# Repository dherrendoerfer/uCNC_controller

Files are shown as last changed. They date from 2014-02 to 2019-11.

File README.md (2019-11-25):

Copyright (C) 2014,2015,2016,2017 D.Herrendoerfer 

# uCNC_controller: A small Arduino CNC

uCNC_controller is a small CNC G-Code interpreting controller for educational or home projects.  
It supports small set of commands and can be configured to behave in several different ways.  
Included in the Extras directory are sample files to replicate a controller circuit board and  
3D files to build a small 3 axis CNC plotter.

### uCNC_controller:
It controls up to three stepper motors via the Arduino stepper library, as well as one servo, and  
two general purpose outputs. It is programmed for simplicity and readability more than for being  
a feature-complete g-code interpreter. It is intended to be a stepping stone for people intending  
to learn about machine control.

### The Extras:
Within the Extras directory there are tools, layout and schematic files, control firmwares to  
extend the basic use example of a simple plotter. Feel free to delve.

Please read the included **uCNC_controller/README.txt** file for more information.  
Please read the included **LICENSE** files and make sure you understand them before redistributing anything from this repo.

### More Information
The original source code of uCNC_controller was developed for this project in 2013  
<a href="http://www.youtube.com/watch?feature=player_embedded&v=rLQajSRnELc
" target="_blank">Direct ink to PCB CNC Plotter</a>

Also, feel free to check out my [YouTube Channel](https://www.youtube.com/channel/UCe9XrOQuQR8SzbB_zRUIf0w "Dirk Herrendoerfers YouTube Channel")
all the source code and project files from the projects  
featured on the channel are hosted here.

### Ready to order PCBs for uCNC_Controller
The circuit boards for the uCNC projects are available for viewing at the EasyEDA online PCB design 
web site and can be ordered directly through JCLPCB from that site. 

The direct link to my project space on EasyEDA is [https://easyeda.com/dherrendoerfer](https://easyeda.com/dherrendoerfer "Dirk Herrendoerfers EasyEDA Projects")

## Notes
- The beta directory contains pre-release versions of the controller firmware.
- To build the uCNC_controller firmware the Arduino stepper library is required.
- The firmware requires a 5V Arduino board with at least 13 digital and 6 Analog I/O ports.  
- Recommended are 32k of flash memory.  
- Among the supported boards are: Arduino Uno, Arduino Nano, Arduino Mega 2560, and many more.
- This is work-in-progress. Check back frequently.

Donations:  
If you would like to make a donation to keep this project and others going you can do so at:  
https://www.paypal.me/dherrendoerfer  
This helps a lot !

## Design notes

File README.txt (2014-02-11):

 *
 * This file is part of uCNC_controller.
 *
 * Copyright (C) 2014  D.Herrendoerfer
 *
 *   uCNC_controller is free software: you can redistribute it and/or modify
 *   it under the terms of the GNU General Public License as published by
 *   the Free Software Foundation, either version 3 of the License, or
 *   (at your option) any later version.
 *
 *   uCNC_controller is distributed in the hope that it will be useful,
 *   but WITHOUT ANY WARRANTY; without even the implied warranty of
 *   MERCHANTABILITY or FITNESS FOR A PARTICULAR PURPOSE.  See the
 *   GNU General Public License for more details.
 *
 *   You should have received a copy of the GNU General Public License
 *   along with uCNC_controller.  If not, see <http://www.gnu.org/licenses/>.
 *

uCNC_controller Readme file:
============================

uCNC_controller is a g-code interpreting controller app that is intended
for use on the Arduino platform. It interprets a number of g-code 
commands and controls a number of unipolar stepper motors (3), some 
digital outputs (2), and number of servos (1) accordingly.
It is intended for use in home or educational projects, and as the 
license states: it comes with no waranty whatsoever. If you use it
and it breaks in your hands, you get to keep all the pieces.

Default configuration:
======================

  Connector   IO-Ports on Arduino nano w. ATMEGA328P
------------>--------------------------------------------
  Stepper 1:  8,9,10,11
  Stepper 2:  4,5,6,7
  Stepper 3:  A5,A4,A3,A2 (digital out 19,18,17,16)               
  12V out 1:  2
  12V out 2:  3
  Laser out:  13
  Servo out:  12
  Unused   :  A0,A1,A6,A7 (A6 and A7 cannot be used as output) 

System Reset and Initialization routine
---------------------------------------
  Upon reset or power up the controller attempts to move all
  axis into their minimal position by traversing the configured
  distance into a solid zero position block - builds should be
  designed to cope with this. 

Device-specific values and devices
==================================

Control ports:
--------------
 - Liquid coolant (M7,M8,M9) controls 12VO port 1
 - Vacuum (M10,M11) controls 12VO port 2
 - Spindle(M3,M4,M5) controls Laser and Servo ports (mode dependent)
 - Tool (TXX) controls Servo (mode dependent)
 - Z value controls Laser (on when Z negative - mode dependent)

Device-specific G-Code commands:
================================
  NOTE: All of these settings can be made in the source code of the
        controller applivation, and should in fact be made there.
        The possibility to change them is intended to make it possible
        to create a controller module that can be shared between 
        several installations, and that is configured by the init
        sequence of its controlling host.

M150: Set Z-Axis mode
---------------------
Defines the mode how the Steppers, the servo and the laser driver are
used by the controller and which codes modify their states
  Mode 0: Stepper 1 is X
          Stepper 2 is Y
          Stepper 3 is Z
          Servo is spindle speed
          Laser is driven by spindle
          
  Mode 1: Stepper 1 is X
          Stepper 2 is Y
          Stepper 3 is Y
          Servo     is Z (down for Z<0)
          Laser     is Z (on for Z<0)

  Mode 2: Stepper 1 is X
          Stepper 2 is Y
          Stepper 3 is Y
          Servo     is Z (+90 to -90)
          Laser     is driven by spindle
          
  Mode 3: Stepper 1 is X
          Stepper 2 is Y
          Stepper 3 is Y
          Servo     is tool
          Laser     is Z (on for Z<0)
          
  Sample:
    M150 S2   ;Sets mode 2
          
M151: Set servo upper position
------------------------------
Sets the maximum value to send to the servo. Range is 0 to 180.

  Sample:
    M151 S170   ;Sets the maximum position to 170

M152: Set servo lower position
------------------------------
Sets the minimum value to send to the servo. Range is 0 to 180.

  Sample:
    M152 S10   ;Sets the minimum position to 10

M153: Set servo tool increment
------------------------------
Sets the increment value to send to the servo depending on the selected tool.

  Sample:
    M153 S10   ;Sets an servo increment of 10 for each selected tool.

M154: Set servo Z factor
------------------------
Sets the ratio between the Z value and the servo position in degrees.

  Note: The Z value at factor 1 is -89 to +90, this also honors the minimum
        and max values set to the servo, so set them to 0 and 180 for full 
        stroke. The sign of this value determines the direction of the servo.

  Sample:
    M154 S0.1  ;Sets ratio to 0.1

M160: Set X-Axis step to mm ratio
---------------------------------
Sets the calibration value of the X-Axis in relation to the steps needed to
travel 1 milimeter. The sign of this value determines the direction of the 
stepper.

  Sample:
    M160 S17.1  ;Sets the ratio of the X-Axis to 17.1 steps per milimeter

M161: Set Y-Axis step to mm ratio
---------------------------------
Sets the calibration value of the Y-Axis in relation to the steps needed to
travel 1 milimeter. The sign of this value determines the direction of the 
stepper.

  Sample:
    M161 S17.1  ;Sets the ratio of the Y-Axis to 17.1 steps per milimeter

M162: Set Z-Axis step to mm ratio
---------------------------------
Sets the calibration value of the Z-Axis in relation to the steps needed to
travel 1 milimeter. The sign of this value determines the direction of the 
stepper.

  Sample:
    M162 S17.1  ;Sets the ratio of the X-Axis to 17.1 steps per milimeter

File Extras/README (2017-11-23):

Copyright (C) 2014,2015,2016 D.Herrendoerfer 

This directory contains additional files for uCNC_controller

Note:
PCB layouts now also available here: https://easyeda.com/dherrendoerfer 

Controller
----------
  The this directory contains the files to recreate a controller
  PCB using uCNC_controller and a G-Code sender.

Controller_v1
-------------
  The this directory contains the files for an updated version
  of the first control board. It also includes the original
  Eagle project files.

Controller_v4
-------------
  The this directory contains the files for an upgraded version
  of the control board. It uses A4988 stepper driver modules that
  allow the use of bipolar steppers. It also includes the original
  Eagle project files.

GcodeWriter
-----------
  This directory contains an updated version of ardGcodeWriter.py
  with a number of improvements from me.
  This was not developed by me, I only fixed a number of bugs in
  the program. As the original has been removed from the net I
  keep my latest version here for reference.
  For more information on the original Author, refer to the source
  code.
  
Hp2xx
-----
  This directory contains a Windows executable of the hp2xx tool.
  This is for reference only, but as the tool appears to be unmaintained
  at this time I keep it here. 

Plotter_v3
----------
  This directory contains the files to recreate a simple plotter that
  can be used with the uCNC_controller firmware.

Plotter_v4
----------
  This directory contains the files to recreate a simple plotter that
  can be used with the uCNC_controller firmware. This one uses NEMA 17 
  steppers.

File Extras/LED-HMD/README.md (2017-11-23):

Copyright (C) 2017 D.Herrendoerfer 

# Simple tools and instructions for building a WS2812 based round display:

The geometry of the display of lines of LEDs with the following length:

(6,10,14,16,18,20,22,22,24,24,24,26,26,26,26,24,24,24,22,22,20,18,16,14,10,6)

Like so:
```
         XXXXXX
       XXXXXXXXXX
     XXXXXXXXXXXXXX
    XXXXXXXXXXXXXXXX
   XXXXXXXXXXXXXXXXXX
  XXXXXXXXXXXXXXXXXXXX
  XXXXXXXXXXXXXXXXXXXX
 XXXXXXXXXXXXXXXXXXXXXX
 XXXXXXXXXXXXXXXXXXXXXX
 XXXXXXXXXXXXXXXXXXXXXX
XXXXXXXXXXXXXXXXXXXXXXXX
XXXXXXXXXXXXXXXXXXXXXXXX
XXXXXXXXXXXXXXXXXXXXXXXX
XXXXXXXXXXXXXXXXXXXXXXXX
 XXXXXXXXXXXXXXXXXXXXXX
 XXXXXXXXXXXXXXXXXXXXXX
 XXXXXXXXXXXXXXXXXXXXXX
  XXXXXXXXXXXXXXXXXXXX
  XXXXXXXXXXXXXXXXXXXX
   XXXXXXXXXXXXXXXXXX
    XXXXXXXXXXXXXXXX
     XXXXXXXXXXXXXX
      XXXXXXXXXX
        XXXXXX
```

The sketch will display the images, the tool will generate the source code
from an image.

There are 2 switches (to GND) on D2 and D3, one will advance to the next image,
the other will apply a variation to the image to make simple animations possible,
like a smily giving a wink.
Pressing any switch for more than 2 seconds turns off the display.

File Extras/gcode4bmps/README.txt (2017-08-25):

 *
 * This file is part of uCNC_controller.
 *
 * Copyright (C) 2017  D.Herrendoerfer
 *
 *   gcode4bmps.py is free software: you can redistribute it and/or modify
 *   it under the terms of the GNU General Public License as published by
 *   the Free Software Foundation, either version 3 of the License, or
 *   (at your option) any later version.
 *
 *   uCNC_controller is distributed in the hope that it will be useful,
 *   but WITHOUT ANY WARRANTY; without even the implied warranty of
 *   MERCHANTABILITY or FITNESS FOR A PARTICULAR PURPOSE.  See the
 *   GNU General Public License for more details.
 *
 *   You should have received a copy of the GNU General Public License
 *   along with uCNC_controller.  If not, see <http://www.gnu.org/licenses/>.
 *
 
gcode4bmps.py:
--------------

Gcode for bitmaps is a very simple tool to transform bitmaps to gcode
for raster engraving. (Engraving line by line, not vector-style)
Images read are converted to grayscale and then interpreted as black
and white (trip value 128).

Installation:
-------------

Gcode4bmps.py was developed for python2.7. It also requires the
prior installation of the python-pillow library and it's development
package (python-pillow-devel).
Futhermore, to read and interpret ps, eps, and pdf files, the ghostscript
package must be installed. (This was only tested on Linux, but should work
with Windows too.)

Usage:
------

Basic usage:

./gcode4bmps.py  -d 300 -i test/tux-bw.gif

This will read the image and generate g-code to engrave it. The output
will be written to output.nc in the current directory (default, unless specified)
You need to supply at least one of:
	- Output size with -x and -y (in mm)
	- Source image DPI with -d 
	- Source image DPCM (dots per cm) with -m 

You can specify the output file name with -g ( '-g -' for standard out, implies using -q )

Using postscript or pdf:
------------------------

/gcode4bmps.py -G -C -d 300 -i test/tux-bw.pdf

Use the -G option to turn on ghostscript transcoding, and also use
the -C option to crop the resulting image (ghostscript output is always a page)

Options available:

Usage: gcode4bmps.py [options]

Options:
  -h, --help            				show this help message and exit
  -i FILE, --imgfile=FILE				read image from this FILE
  -g FILE, --gcodefile=FILE				write gcode to this FILE
  -s STEPSIZE, --stepsize=STEPSIZE		stepsize of a single output pixel/dot (bit/laser size)
  -x XSIZE, --xsize=XSIZE				x size of the output gcode in mm
  -y YSIZE, --ysize=YSIZE				y size of the output gcode in mm
  -d DPI, --dpi=DPI     				source image dpi value
  -m DPCM, --dpcm=DPCM  				source image dpcm value
  -n, --negative        				invert the image
  -p PASSES, --passes=PASSES			number of passes over a line
  -u, --upwards         				process from bottom to top
  -z ZDOWN, --zdown=ZDOWN				value for Z axis down
  -Z ZUPPER, --zupper=ZUPPER			value for Z axis up
  -b, --bidirectional   				engrave in both directions
  -B, --backlash        				compensate for backlash in unidirectional engraving
  -f FEED1, --feed1=FEED1				set feedrate for G1 moves
  -F FEED0, --feed0=FEED0				set feedrate for G0 moves
  -M speed, --spindle=speed             enable insertion of spindle start and stop with selected speed
  -C, --crop            				crop the image to only plot the used area
  -G, --ghostscript     				use ghostscript to import postscript image files
  -q, --quiet           				don't print status messages to stdout

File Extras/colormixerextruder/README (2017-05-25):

COLORMIXEXTRUDER:

This is the attempt to build a simple color mixing
extruder driver board and controller to drive a 
diamond extruder without modifying an existing 
3D printers driver board to support more stepper
drivers.

The signals of the stepper controller board from
the 3D printers extruder stepper are passed to the 
controller as well as the serial data comming from
the PC.

The controller scans the incommming serial g-code 
data for occurences of the TXX code and sets the
desired color for that tool.

This has been designed for my uControl_v1 driver 
board but should be easily adapted for other driver
boards.

This is alpha software - expect it to be broken.

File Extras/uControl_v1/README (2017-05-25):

Included here is a prototype layout for a controller circuit.

The uControl board is different from the previous versions and 
requires a different firmware than the other versions.

Features are:
--------------
Support for 3 bipolar steppers using A4988 Polulu driver modules.
Support for 1 servo
Support for 8 input lines 6 bare, 2 as switch inputs
Support for 1 high load output (5A/PWM)
Support for breakout of serial and reset lines

uControl_v1.sch
----------------
  The layout schematic file

uControl_v1.brd
----------------
  The layout source file (just the layout)

uControl_v1.ps, uControl_v1.pdf
--------------------------------
  Exported layout formats of the above board

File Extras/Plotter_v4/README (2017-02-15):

Sample stl model files to make a plotter using a 3D printer.

Other needed parts list:

The 3D parts in this directory (Plotter-v4-AllParts.stl) once, 
and the parts for the pen-holder from the Plotter_v3 directory.

Other parts required:

Quan.|  Item
-----+----------------------------------------------
4	  	5mm steel rod. 
some	Brass tube, 6mm outer, 5mm inner diameter
2 		NEMA 17 Stepper Motors
some	T2 or T2.5 belt 6mm width for X and Y Axis
2		T2 or T2.5 belt pulleys
2 		Ball bearings 11/5mm
1 		20mm micro servo
8		Magnets (5/1mm)
some 	PCB prototyping board

Parts list for the controller:

Quan.|  Item
-----+----------------------------------------------
1 		Arduino nano with 328P 
2		Polulu Stepper driver modules
1		7805 Power regulator
1		Capacitor 1000uF/25V (input smoothing)
1		Capacitor 100uF/10V  (5V smoothing)
		Male Connectors for Motors and Arduino
		Female pin connectors for Servo and Laser out.
Optional
		Mosfet and Resistor for Laser driver
		(Choose what you need, depends on laser type)

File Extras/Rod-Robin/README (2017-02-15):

This list is work-in-progress (might be incomplete)

Sample stl model files to make the Rod-Robin CNC using a 3D printer.

Other needed parts list:

The 3D parts in this directory according to list below.

Quan.|  Item
-----+----------------------------------------------
 1   | Rod-Robin-Pillar-A.stl
 1   | Rod-Robin-Pillar-B.stl
 2   | Rod-Robin-H-Base-A.stl
 2   | Rod-Robin-H-Base-B.stl
 1   | Rod-Robin-H-Base-C.stl  
 4   | Rod-Robin-H-Base-D.stl  
 2   | Rod-Robin-Table-A.stl  
 1   | Rod-Robin-Z-Base-A.stl  

Other parts required:

Quan.|  Item
-----+----------------------------------------------
 7	 | 	LM5UU Linear bearings. 
 6   |	11x5x4 Bearings 
 2 	 |	NEMA 17 Stepper Motors
 2	 |	T2 or T2.5 belt 6mm width
 2	 |	T2 or T2.5 belt pulleys
 2   |  Microswitches
 4   |  5mm Stainless Steel rod 
     |    2x for X-Axis 
     |    2x for Y-Axis
16	 |  M5 Threaded Rod
many |  M5 Nuts
 1   |  Table board 
     |    2 to 4mm steel or aluminium 
 
Also needed:
  Glue (Pattex Clasic)
  Nut-Lock glue ( Locktite medium )

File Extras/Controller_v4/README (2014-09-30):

Included here is a prototype layout for a controller circuit.

The Controller_v4 is different from the previous versions and 
requires a different firmware than the other versions.

New features are:
-----------------
Support for 3 bipolar Steppers using A4988 Polulu driver modules.
Support for 1 unipolar Stepper using a ULN2003
Support for 1 Servo 
Support for 3 GPIO outputs 500mA
Support for 1 high load output (5A)
Support for 2 signal inputs

Controller_v4.sch
-----------------
  The layout schematic file

Controller_v4.brd
-----------------
  The layout source file (just the layout)

Controller_v4.hpgl, Controller_v4.ps, Controller_v4.pdf
-------------------------------------------------------
  Exported layout formats of the above board

Controller_v4.hpgl.nc
---------------------
  A g-code sample file that will produce a plot of the above
  board using the included board and firmware.

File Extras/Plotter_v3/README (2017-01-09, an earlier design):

Sample stl model files to make a plotter using a 3D printer.

Other needed parts list:

The 3D parts in this directory ( Plotter-v3-PenMount-2.stl twice)
or the Plotter-v3-AllParts.stl once, it contains everything except the
table, which is optional and can easily be replaced by some prototyping
board.

Please note that the maximum size of this plotter can be quite large,
but to minimize the elastic effect of the nylon string I advise to keep
the X axis at about 20cm and the Y Axis at 16cm. The steel rods need to
be 2cm larger for the X axis (24cm) and 6cm for the Y Axis (24cm).

Other parts required:

Quan.|  Item
-----+----------------------------------------------
4	  	5mm steel rod. 
some	Brass tube, 6mm outer, 5mm inner diameter
2 		Stepper Motors 28YBJ-48 (12V or 5V)
2 		Ball bearings 4/2mm
1 		20mm micro servo
8		Magnets (5/1mm)
some	Nylon string or fishing line
some	PCB prototyping board

Parts list for the controller:

Quan.|  Item
-----+----------------------------------------------
1 		Arduino nano with 328P 
2		ULN2003 or ULN2004
1		7805 Power regulator
1		Capacitor 1000uF/25V (input smoothing)
1		Capacitor 100uF/10V  (5V smoothing)
		Male Connectors for Motors and Arduino
		Female pin connectors for Servo and Laser out.
Optional
		Mosfet and Resistor for Laser driver
		(Choose what you need, depends on laser type)

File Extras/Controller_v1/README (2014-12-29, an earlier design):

Included here is a prototype layout for a controller circuit.
This controller circuit is identical to the Controller.brd 
with the exception that the Laser is driven with 12V, not 5V.

-- Beta warning: this has not jet been fully tested by me.

Controller_v1.brd
--------------
  The layout source file

Controller_v1.sch
--------------
  The schematic source file.

  Controller_v1.hpgl, Controller_v1.ps
--------------------------------------
  Exported layout formats of the above board

Controller_v1.hpgl.nc
---------------------
  A g-code sample file that will produce a plot of the above
  board using the included board and firmware.

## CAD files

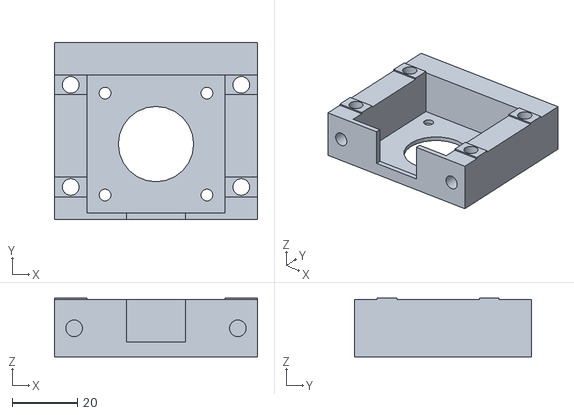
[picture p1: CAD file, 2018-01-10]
Extras/Plotter_v4/Plotter_v4_Table_Base_1.stl
62.0 x 54.0 x 18.0

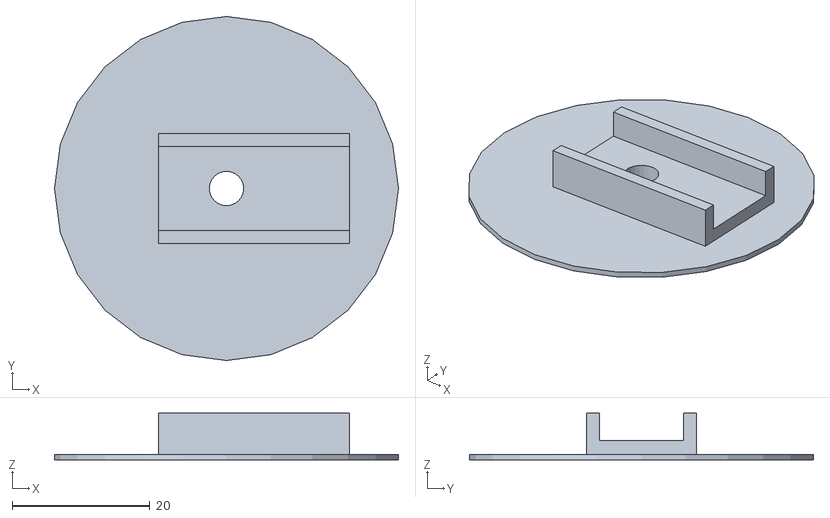
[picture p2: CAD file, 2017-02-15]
Extras/Rod-Robin/Laser-Tool/Rod-Robin-Laser-Tool-C.stl
50.0 x 50.0 x 6.80

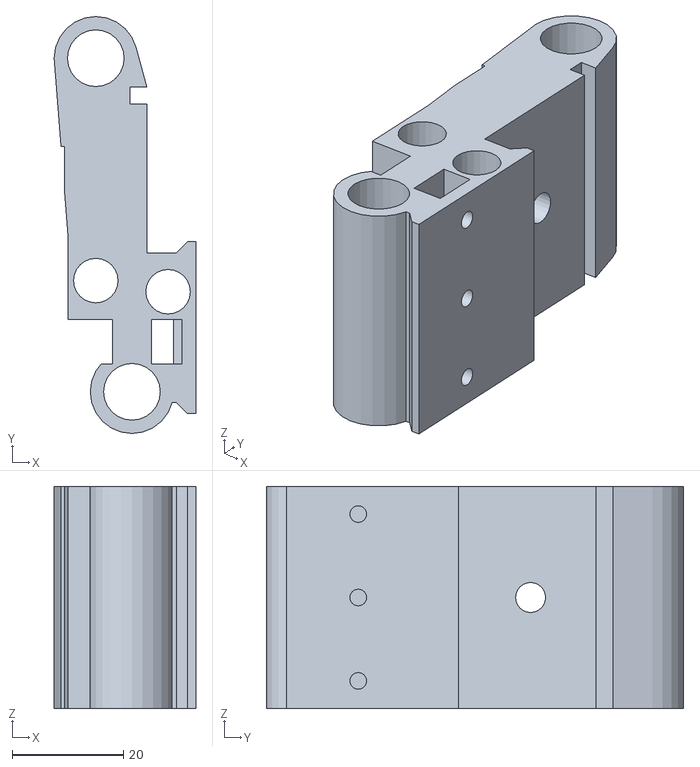
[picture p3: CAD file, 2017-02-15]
Extras/Rod-Robin/Rod-Robin-Z-Base.stl
25.5 x 75.0 x 40.0

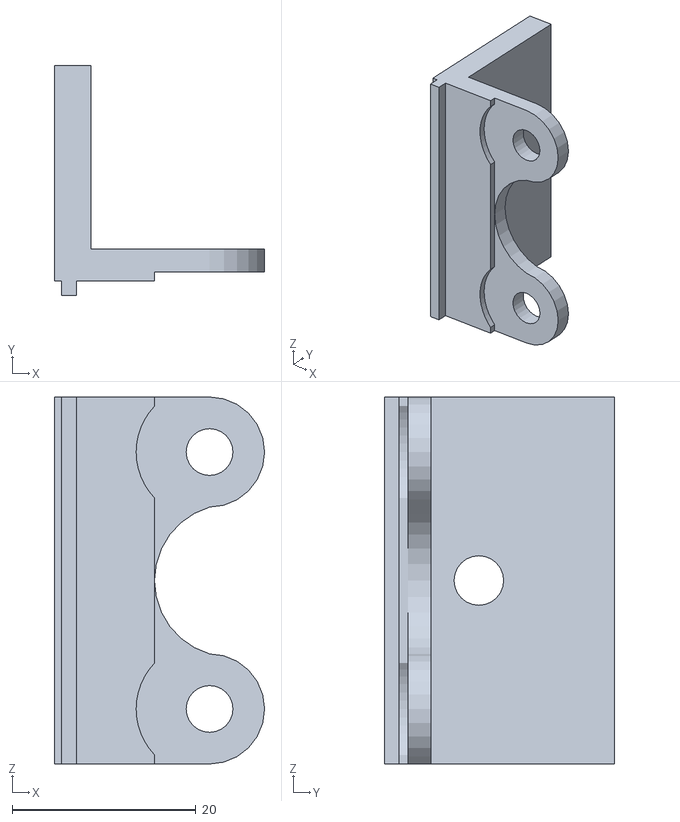
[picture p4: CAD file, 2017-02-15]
Extras/Rod-Robin/Z-Axis-Tool/Rod-Robin-Z-Tool_B.stl
22.9 x 25.1 x 40.0

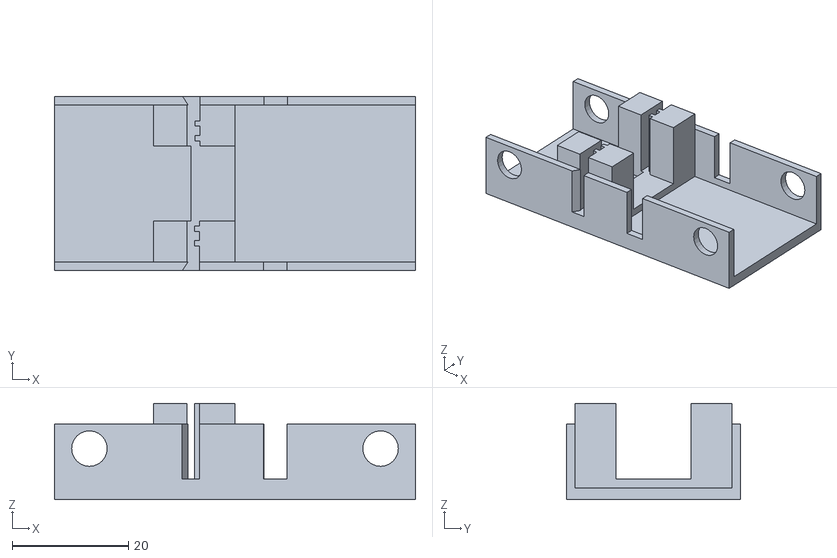
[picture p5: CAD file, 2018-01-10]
Extras/Plotter_v4/Plotter_v4_Table_Sled.stl
62.0 x 30.0 x 16.5

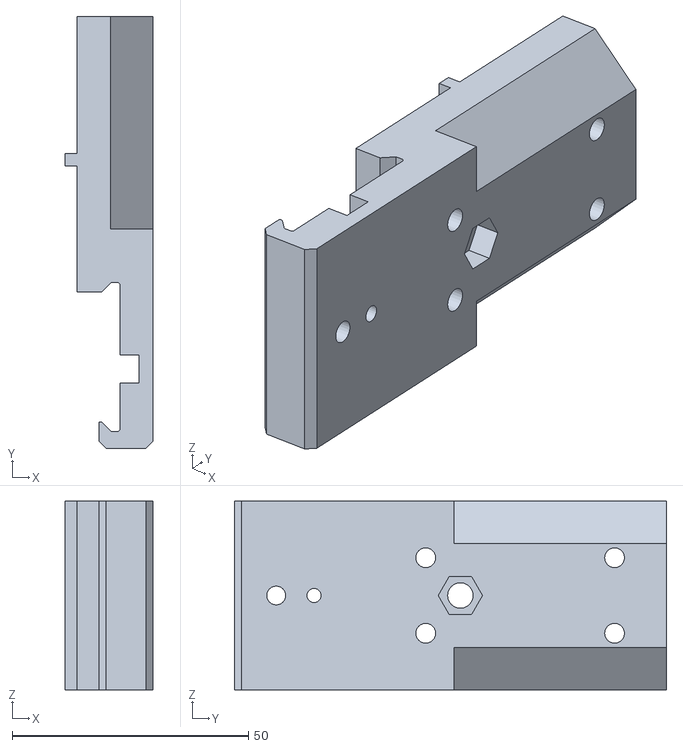
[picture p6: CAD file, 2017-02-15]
Extras/Rod-Robin/Laser-Tool/Rod-Robin-Laser-Tool-A.stl
18.6 x 91.5 x 40.0

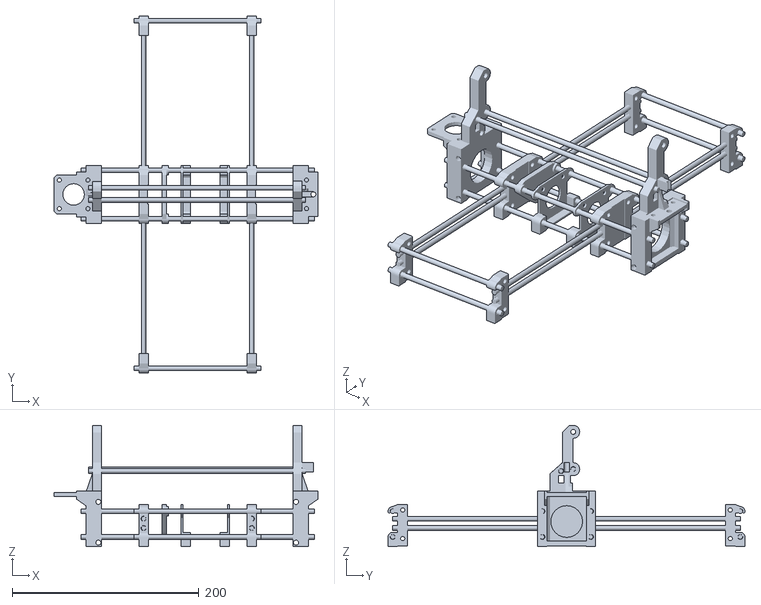
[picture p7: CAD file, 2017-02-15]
Extras/Rod-Robin/Rod-Robin-v2.stl
282.5 x 382.0 x 130.0

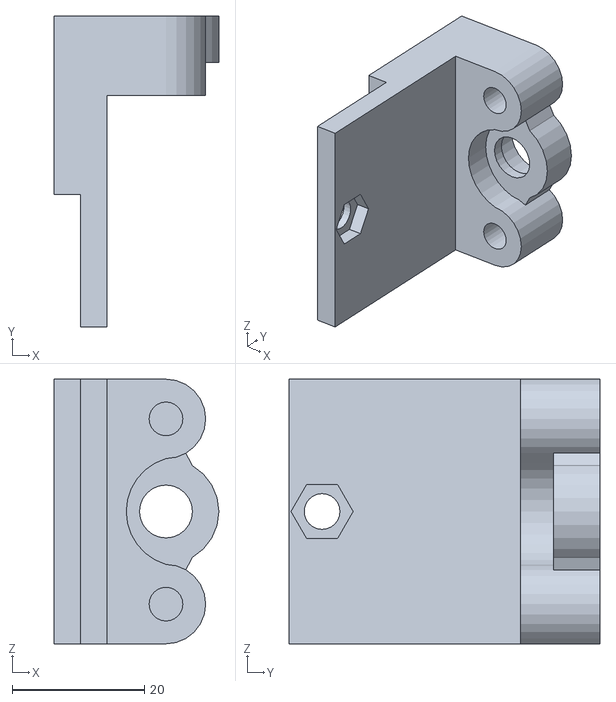
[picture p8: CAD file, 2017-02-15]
Extras/Rod-Robin/Z-Axis-Tool/Rod-Robin-Z-Tool_C.stl
24.9 x 47.0 x 40.0

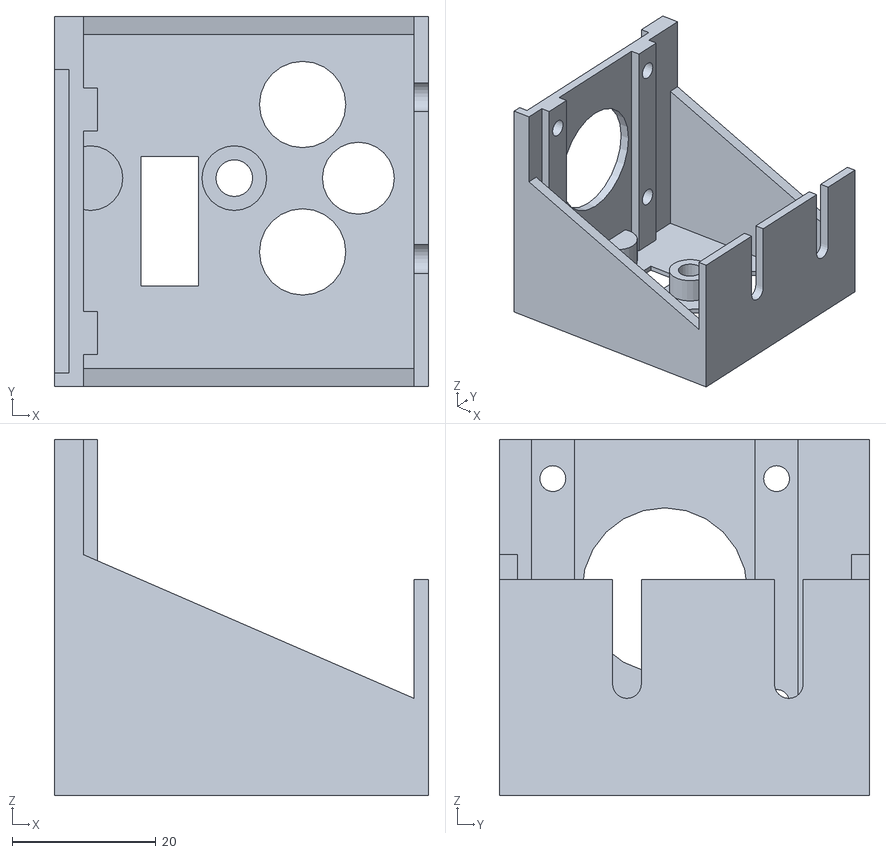
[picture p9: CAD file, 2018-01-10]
Extras/Plotter_v4/Plotter_v4_Pillar_1.stl
52.0 x 51.5 x 49.5

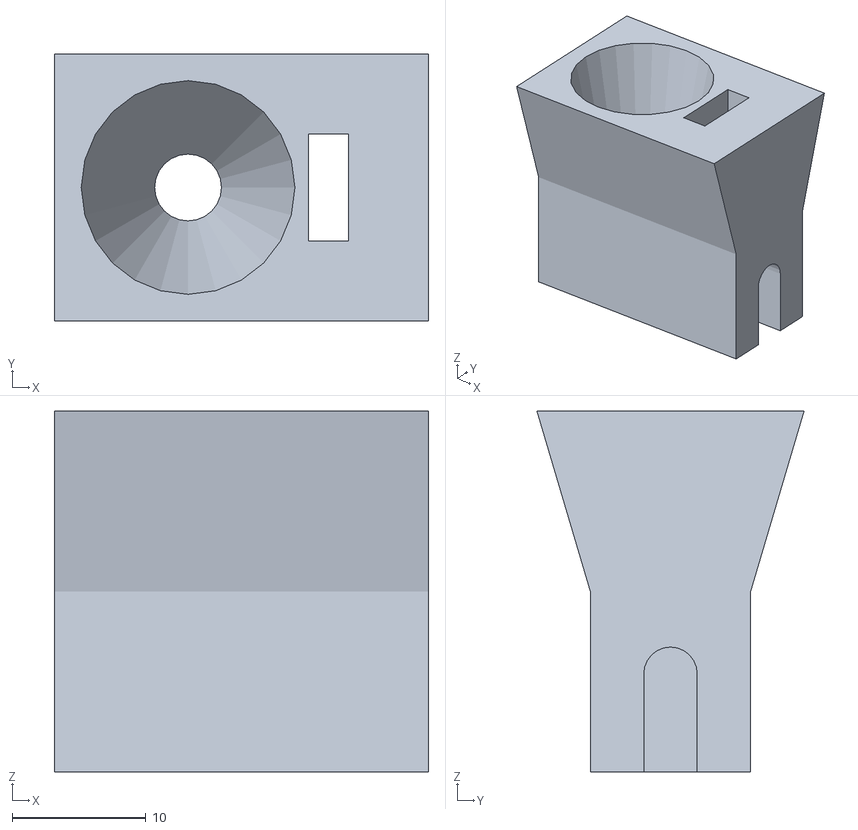
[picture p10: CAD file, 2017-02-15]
Extras/Rod-Robin/Laser-Tool/Rod-Robin-Laser-Tool-B.stl
28.0 x 20.0 x 27.0

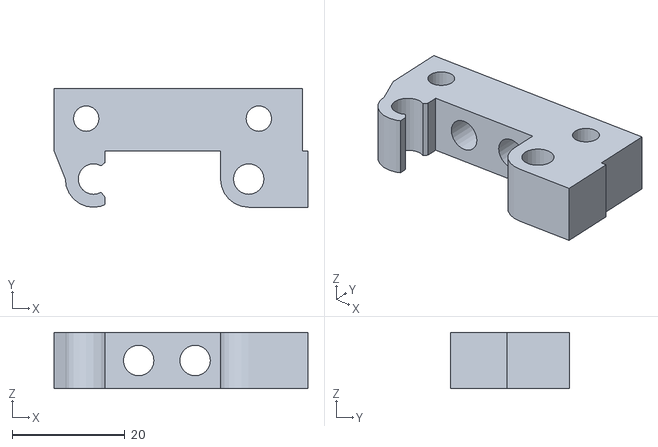
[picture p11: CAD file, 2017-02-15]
Extras/Rod-Robin/Rod-Robin-H-Base-D.stl
45.0 x 21.0 x 10.0

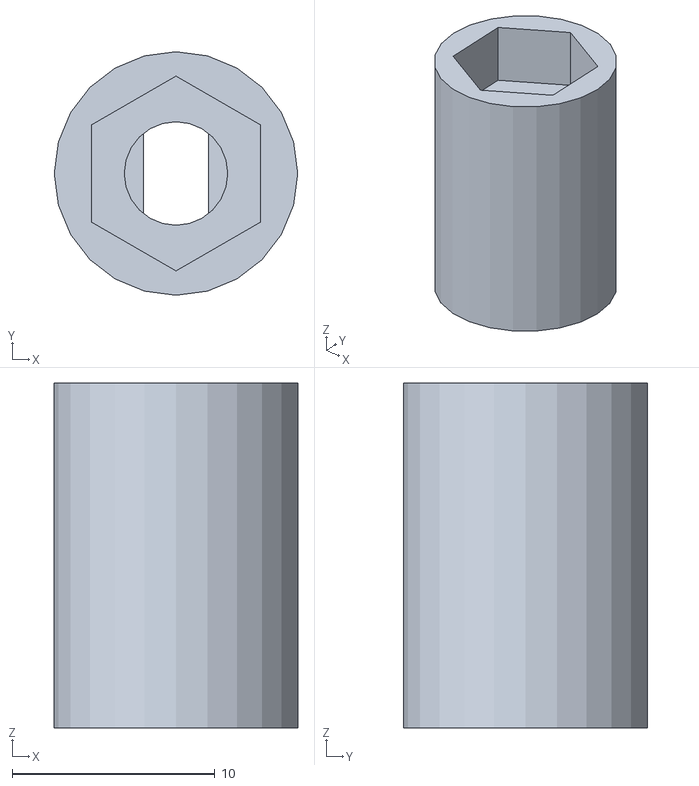
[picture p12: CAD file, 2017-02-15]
Extras/Rod-Robin/Z-Axis-Tool/Rod-Robin-Z-Tool_F.stl
12.0 x 12.0 x 17.0

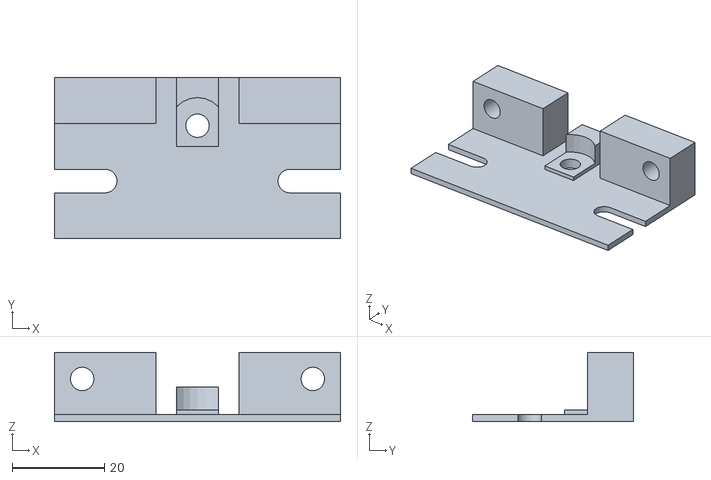
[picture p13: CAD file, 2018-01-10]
Extras/Plotter_v4/Plotter_v4_Table_Base_2.stl
62.0 x 35.0 x 15.0

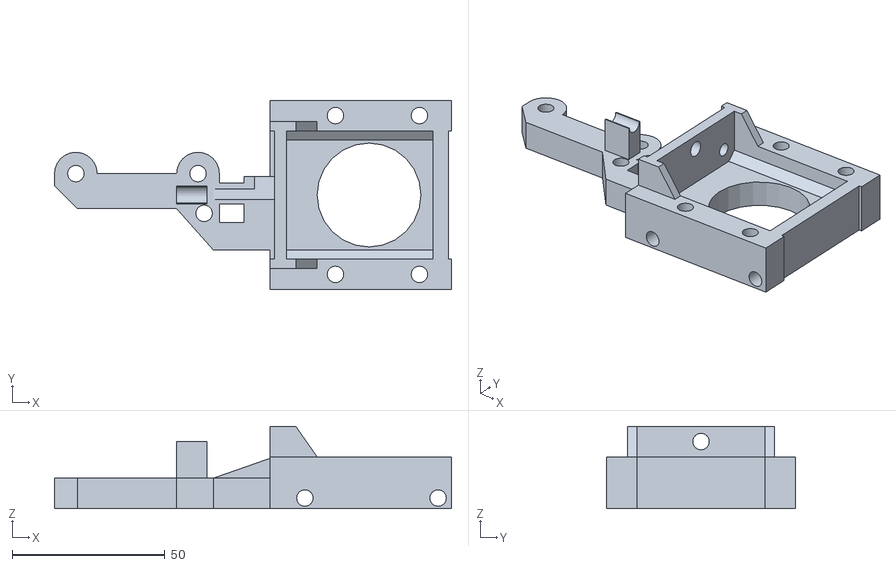
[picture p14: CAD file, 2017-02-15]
Extras/Rod-Robin/Rod-Robin-Pillar-A.stl
130.0 x 62.0 x 27.0

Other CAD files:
Extras/Rod-Robin/Z-Axis-Tool/Rod-Robin-Z-Tool_A.stl
Extras/Plotter_v4/Plotter_v4_Pillar_2.stl
Extras/Rod-Robin/Rod-Robin-Pillar-B.stl
Extras/Rod-Robin/Z-Axis-Tool/Rod-Robin-Z-Tool_E.stl
Extras/Plotter_v3/Plotter-v3-AllParts.stl
Extras/Plotter_v3/Plotter-v3-x-bridge-1.stl
Extras/Plotter_v3/Plotter-v3-x-bridge-2.stl
Extras/Plotter_v3/Plotter-v3-x-sled-1.stl
Extras/Plotter_v3/Plotter-v3-y-bridge-1.stl
Extras/Plotter_v3/Plotter-v3-y-bridge-2.stl
Extras/Plotter_v3/Plotter-v3-y-bridge-3.stl
Extras/Plotter_v3/Plotter-v3-y-bridge-4.stl
Extras/Plotter_v3/Plotter-v3-z-PenMount-1.stl
Extras/Plotter_v3/Plotter-v3-z-PenMount-2.stl
Extras/Plotter_v3/Plotter-v3-z-PenMount-3.stl
Extras/Plotter_v3/Plotter-v3-z-PenMount-3a.stl
Extras/Plotter_v3/Plotter-v3-z-PenMount-4.stl
Extras/Plotter_v4/Plotter_v4_AllParts.stl
Extras/Plotter_v4/Plotter_v4_Tool_Sled.stl
Extras/Rod-Robin/Rod-Robin-H-Base-A.stl
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

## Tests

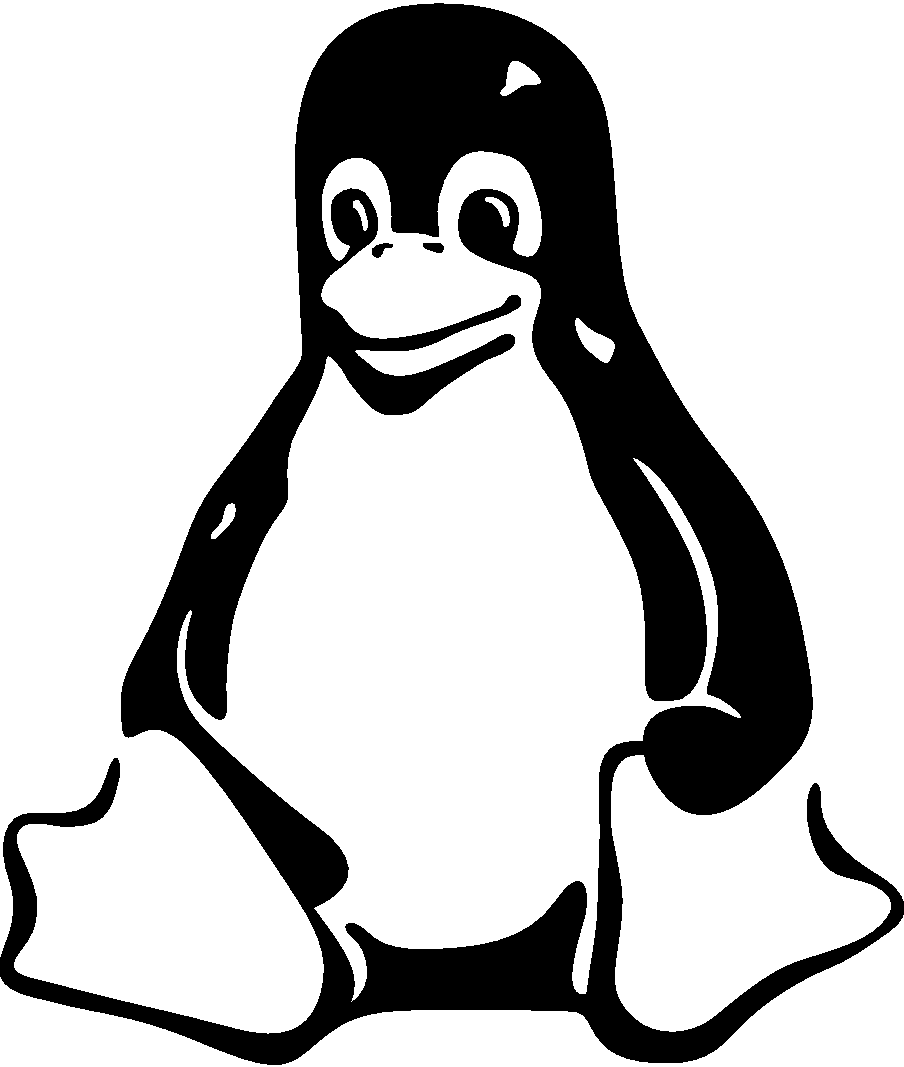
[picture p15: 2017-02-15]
Extras/gcode4bmps/test/tux-bw.gif

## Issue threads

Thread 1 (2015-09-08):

Rod lengths!

zorgrian, 2015-09-08:
## Size matters

I would like to know the lengths of the rods used in this CNC machine. I have looked hard at contents of this repository. I have also watched the great videos by Dirk on youtube.
I want to make one of these things or something like it. I should like to know the lengths of the 5mm rod used in the current designs as a starting place.

dherrendoerfer, 2018-01-10:
The rod lengths are basically up to the person building it.
For a 160x100mm work area I'd use 220mm rod for the X, and 180mm for the Y Axis.

Closed 2018-01-10.

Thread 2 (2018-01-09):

STL files for Plotter_v4

pevire, 2018-01-09:
Hello, could you upload .stl files for every part of Plotter_v4?

I'd like to print every part separately and I really don't know how to split parts in the file wich contents all the parts together.

Thanks in advance.

dherrendoerfer, 2018-01-10:
Uploaded.
Cheers !

pevire, 2018-01-11:
Thanks a lot.

2018-01-10 20:55 GMT+01:00 dherrendoerfer <notifications@github.com>:

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

laziiii, 2018-01-12:
hello this is the part of cnc plotter I lived in the city could send me these costly parts

Closed 2018-01-10.

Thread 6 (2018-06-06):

Universal G code sender reports "Grbl has not finished booting"

numberformat, 2018-06-06:
I am using the uCNC_controller board along with this firmware to control a Etch-a-sketch. I am using The Universal G code sender to send G codes to the Arduino Nano. However the sender is trying to find the GRBL version however the startup message has changed so much that its having a hard time.  Could you please look into this? I think you may be able to print the original version message on the prior line.

I inserted "Grbl 0.81" before the line in question and it worked fine. UGS was able to detect it.
```c
  Serial.println("Grbl 0.81");
  Serial.println("uCNC_controller (compatible: Grbl v0.81, Repetier 0.80, E3D v1.00)");
```

numberformat, 2018-06-08:
Never mind. I thought this was built on top of Grbl.

Closed 2018-06-08.

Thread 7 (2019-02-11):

Rod-Robin cad files?

Aianir, 2019-02-11:
Would you be able to share the cad files for the Rod-Robin? I'd like to adapt them to using the 8mm rods, threaded rods and bearings that I already have.

dherrendoerfer, 2019-02-16:
I can't share them publicly on github , because the of the license agreement with SketchUp, but I can share them privately.

Aianir, 2019-02-18:
That will work! I added you to a private repository here on github, if you can share them there that would be great!

Closed 2019-03-03.

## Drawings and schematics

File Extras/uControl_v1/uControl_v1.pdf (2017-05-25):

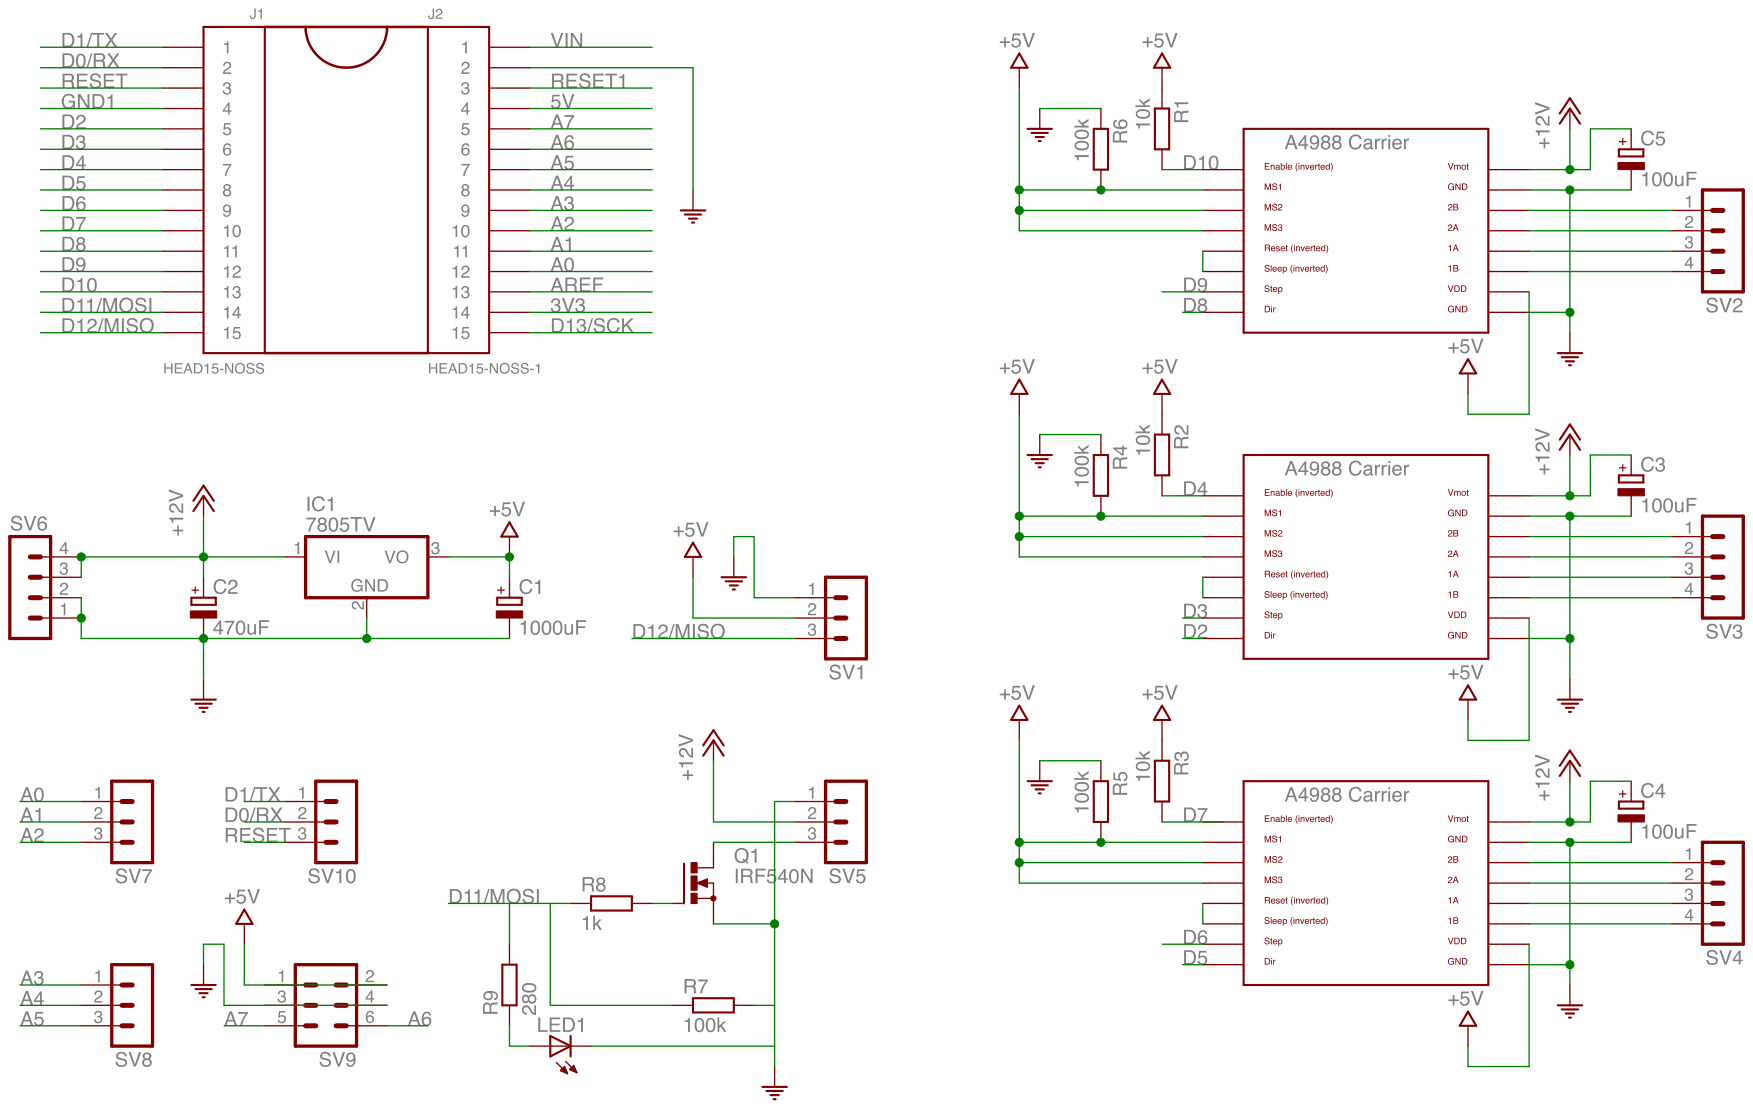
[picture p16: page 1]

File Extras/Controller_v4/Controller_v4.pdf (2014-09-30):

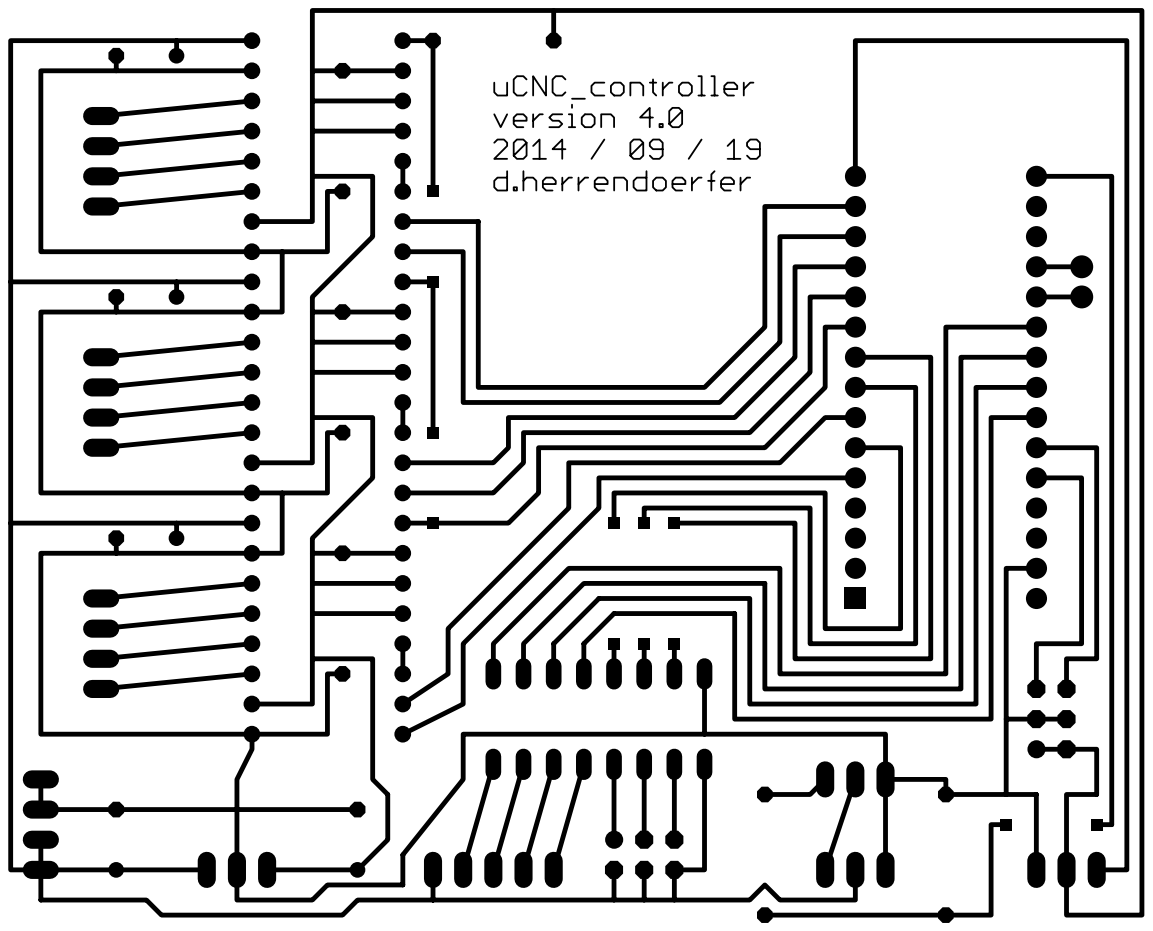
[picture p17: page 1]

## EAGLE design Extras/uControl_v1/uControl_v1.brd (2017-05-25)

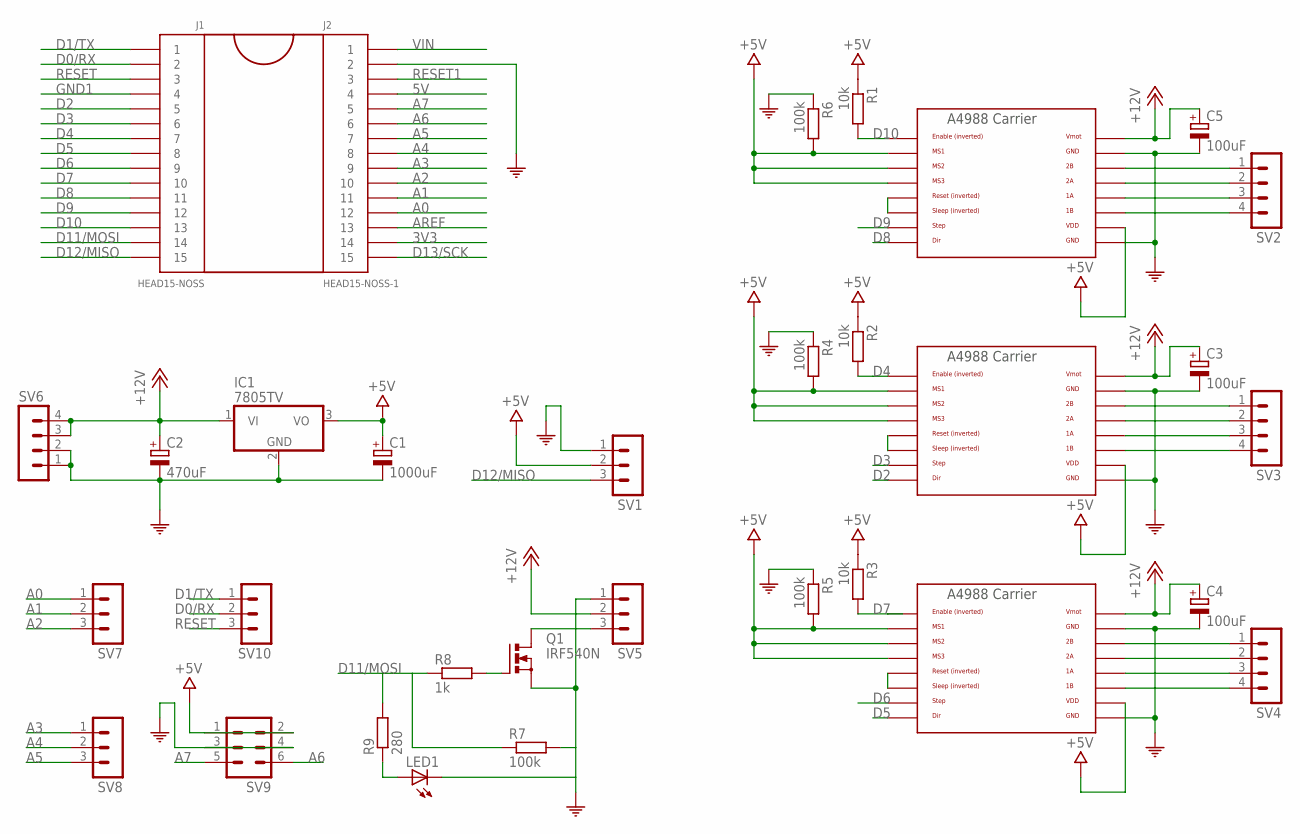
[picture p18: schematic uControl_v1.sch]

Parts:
C1: 1000uF; TAP5-70
C2: 470uF; TAP5-70
C3, C4, C5: 100uF; TAP5-70
IC1: 7805TV; TO220V
J1: HEAD15-NOSS
J2: HEAD15-NOSS-1
LED1: LED3MM
Q1: IRF540N; TO220BV
R1, R2, R3: 10k; 0207/10
R4, R5, R6, R7: 100k; 0207/10
R8: 1k; 0207/10
R9: 280; 0207/10
SV1, SV5, SV7, SV8, SV10: MA03-1
SV2, SV3, SV4, SV6: MA04-1
SV9: MA03-2
U$3: POLOLU_A4983CARRIER; A4988BREAKOUT
U$4, U$5: A4988BREAKOUT

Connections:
3V3: J2.14
5V: J2.4
+5V: C1.+, IC1.3 (VO), R1.1, R2.1, R3.1, R4.2, R5.2, R6.2, SV1.2, SV9.1, SV9.2, U$3.MS1, U$3.MS2, U$3.MS3, U$3.VDD, U$4.MS1, U$4.MS2, U$4.MS3, U$4.VDD, U$5.MS1, U$5.MS2, U$5.MS3, U$5.VDD
+12V: C2.+, C3.+, C4.+, C5.+, IC1.1 (VI), SV5.2, SV6.3, SV6.4, U$3.VMOT, U$4.VMOT, U$5.VMOT
A0: J2.12, SV7.1
A1: J2.11, SV7.2
A2: J2.10, SV7.3
A3: J2.9, SV8.1
A4: J2.8, SV8.2
A5: J2.7, SV8.3
A6: J2.6, SV9.6
A7: J2.5, SV9.5
AREF: J2.13
COM: C1.-, C2.-, C3.-, C4.-, C5.-, IC1.2 (GND), J2.2, LED1.K (C), Q1.S, R4.1, R5.1, R6.1, R7.2, SV1.1, SV5.1, SV6.1, SV6.2, SV9.3, SV9.4, U$3.GND, U$3.GND@0 (GND), U$4.GND, U$4.GND@0 (GND), U$5.GND, U$5.GND@0 (GND)
D0/RX: J1.2, SV10.2
D1/TX: J1.1, SV10.1
D2: J1.5, U$5.DIR
D3: J1.6, U$5.STEP
D4: J1.7, R2.2, U$5.EN
D5: J1.8, U$4.DIR
D6: J1.9, U$4.STEP
D7: J1.10, R3.2, U$4.EN
D8: J1.11, U$3.DIR
D9: J1.12, U$3.STEP
D10: J1.13, R1.2, U$3.EN
D11/MOSI: J1.14, R7.1, R8.1, R9.2
D12/MISO: J1.15, SV1.3
D13/SCK: J2.15
GND1: J1.4
unnamed: LED1.A, R9.1
unnamed: U$4.RST, U$4.SLP (SLEEP)
unnamed: SV2.1, U$3.2B
unnamed: U$3.RST, U$3.SLP (SLEEP)
unnamed: U$5.RST, U$5.SLP (SLEEP)
unnamed: SV2.2, U$3.2A
unnamed: SV2.3, U$3.1A
unnamed: SV2.4, U$3.1B
unnamed: SV3.1, U$5.2B
unnamed: SV3.2, U$5.2A
unnamed: SV3.3, U$5.1A
unnamed: SV3.4, U$5.1B
unnamed: SV4.1, U$4.2B
unnamed: SV4.2, U$4.2A
unnamed: SV4.3, U$4.1A
unnamed: SV4.4, U$4.1B
unnamed: Q1.D, SV5.3
unnamed: Q1.G, R8.2
RESET: J1.3, SV10.3
RESET1: J2.3
VIN: J2.1

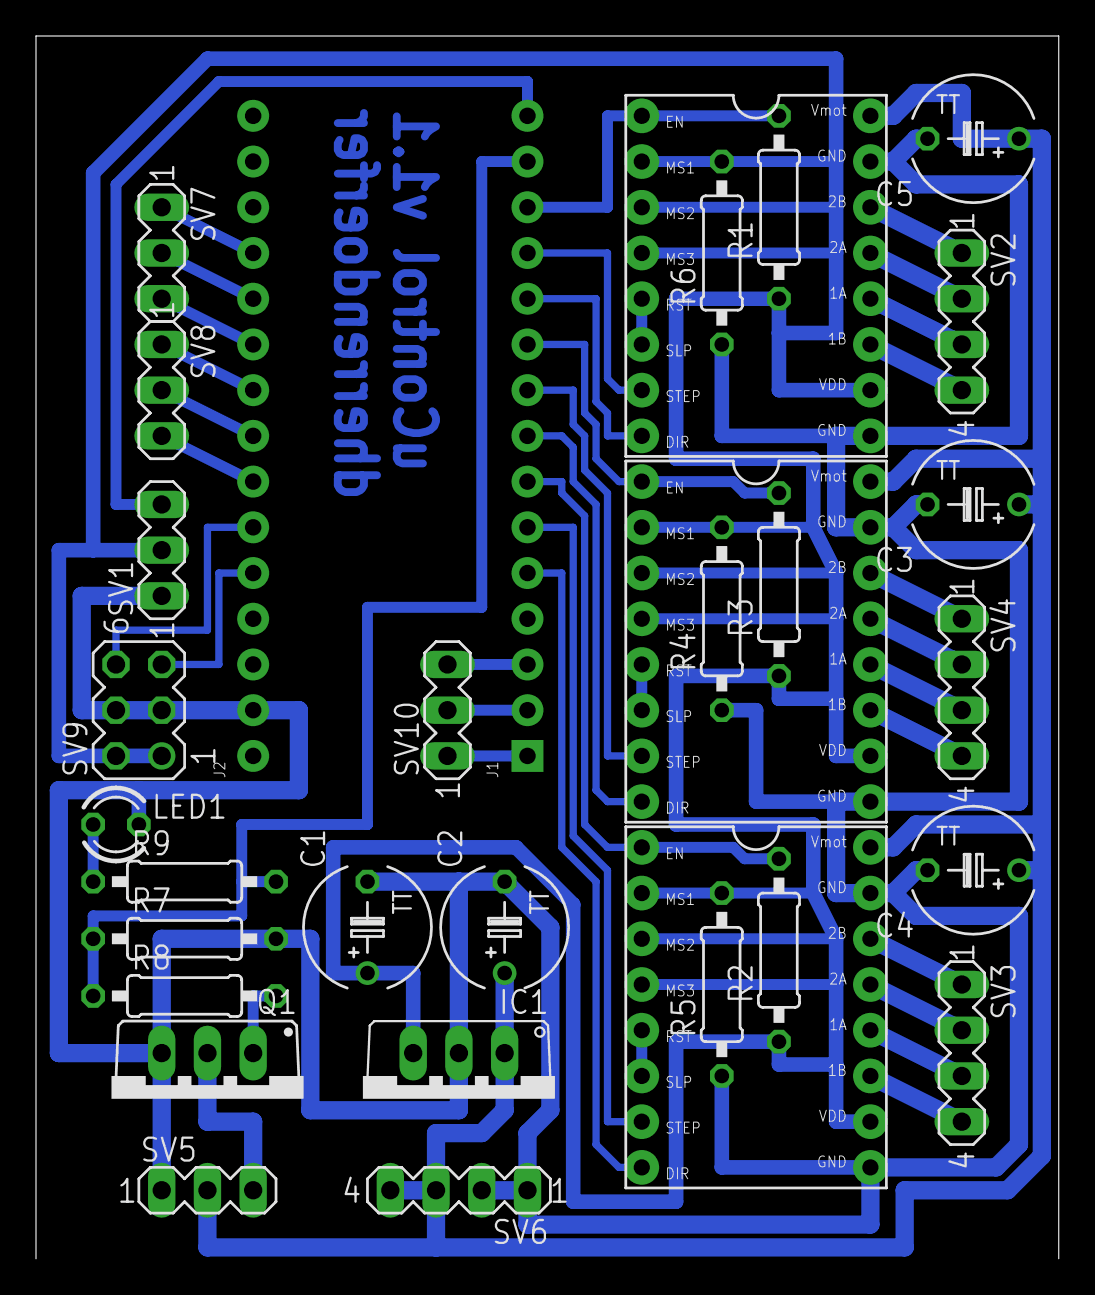
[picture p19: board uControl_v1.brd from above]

Board: 2 copper layers, 56.8 x 67.9 mm, 32 parts (0 on the bottom side), 43 nets.

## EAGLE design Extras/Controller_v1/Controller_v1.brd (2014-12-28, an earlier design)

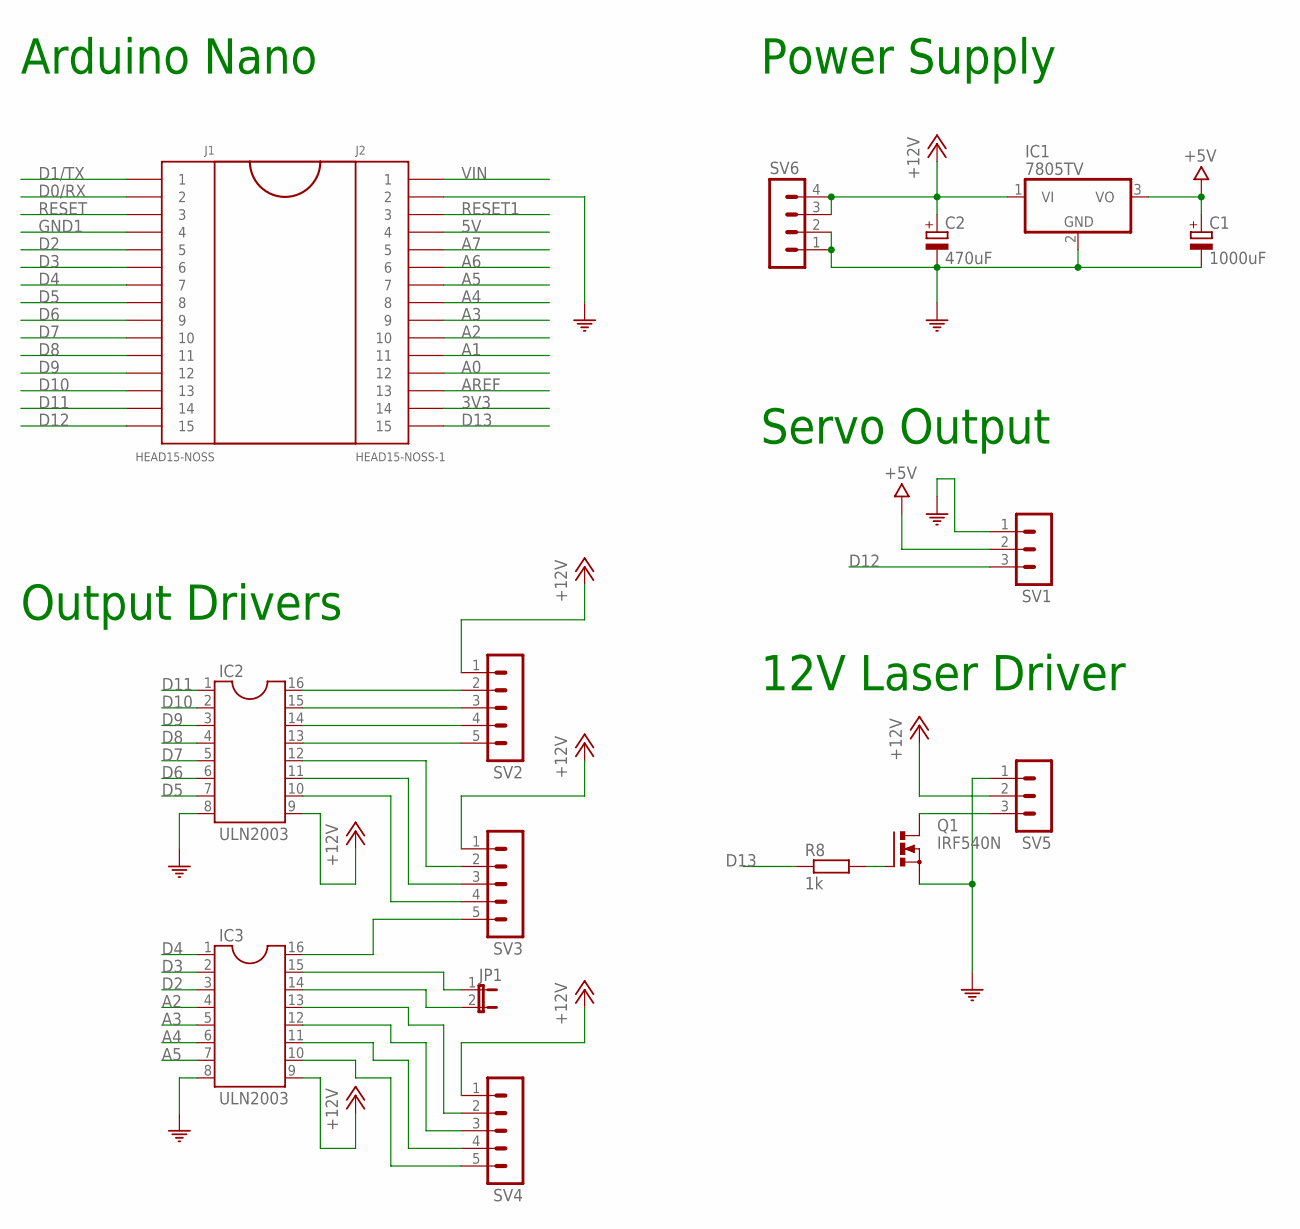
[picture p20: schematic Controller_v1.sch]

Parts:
C1: 1000uF; TAP5-70
C2: 470uF; TAP5-70
IC1: 7805TV; TO220V
IC2, IC3: ULN2003; DIL16
J1: HEAD15-NOSS
J2: HEAD15-NOSS-1
JP1: JP1E; JP1
Q1: IRF540N; TO220BV
R8: 1k; 0207/10
SV1, SV5: MA03-1
SV2, SV3, SV4: MA05-1
SV6: MA04-1

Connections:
3V3: J2.14
5V: J2.4
+5V: C1.+, IC1.3 (VO), SV1.2
+12V: C2.+, IC1.1 (VI), IC2.9, IC3.9, SV2.1, SV3.1, SV4.1, SV5.2, SV6.3, SV6.4
A0: J2.12
A1: J2.11
A2: IC3.4, J2.10
A3: IC3.5, J2.9
A4: IC3.6, J2.8
A5: IC3.7, J2.7
A6: J2.6
A7: J2.5
AREF: J2.13
COM: C1.-, C2.-, IC1.2 (GND), IC2.8, IC3.8, J2.2, Q1.S, SV1.1, SV5.1, SV6.1, SV6.2
D0/RX: J1.2
D1/TX: J1.1
D2: IC3.3, J1.5
D3: IC3.2, J1.6
D4: IC3.1, J1.7
D5: IC2.7, J1.8
D6: IC2.6, J1.9
D7: IC2.5, J1.10
D8: IC2.4, J1.11
D9: IC2.3, J1.12
D10: IC2.2, J1.13
D11: IC2.1, J1.14
D12: J1.15, SV1.3
D13: J2.15, R8.1
GND1: J1.4
unnamed: IC3.15, JP1.1
unnamed: IC3.14, JP1.2
unnamed: IC3.13, SV4.2
unnamed: IC3.12, SV4.3
unnamed: IC3.16, SV3.5
unnamed: IC3.11, SV4.4
unnamed: IC3.10, SV4.5
unnamed: Q1.D, SV5.3
unnamed: Q1.G, R8.2
unnamed: IC2.16, SV2.2
unnamed: IC2.15, SV2.3
unnamed: IC2.14, SV2.4
unnamed: IC2.13, SV2.5
unnamed: IC2.12, SV3.2
unnamed: IC2.11, SV3.3
unnamed: IC2.10, SV3.4
RESET: J1.3
RESET1: J2.3
VIN: J2.1

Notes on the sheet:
Arduino Nano
Output Drivers
Power Supply
Servo Output
12V Laser Driver

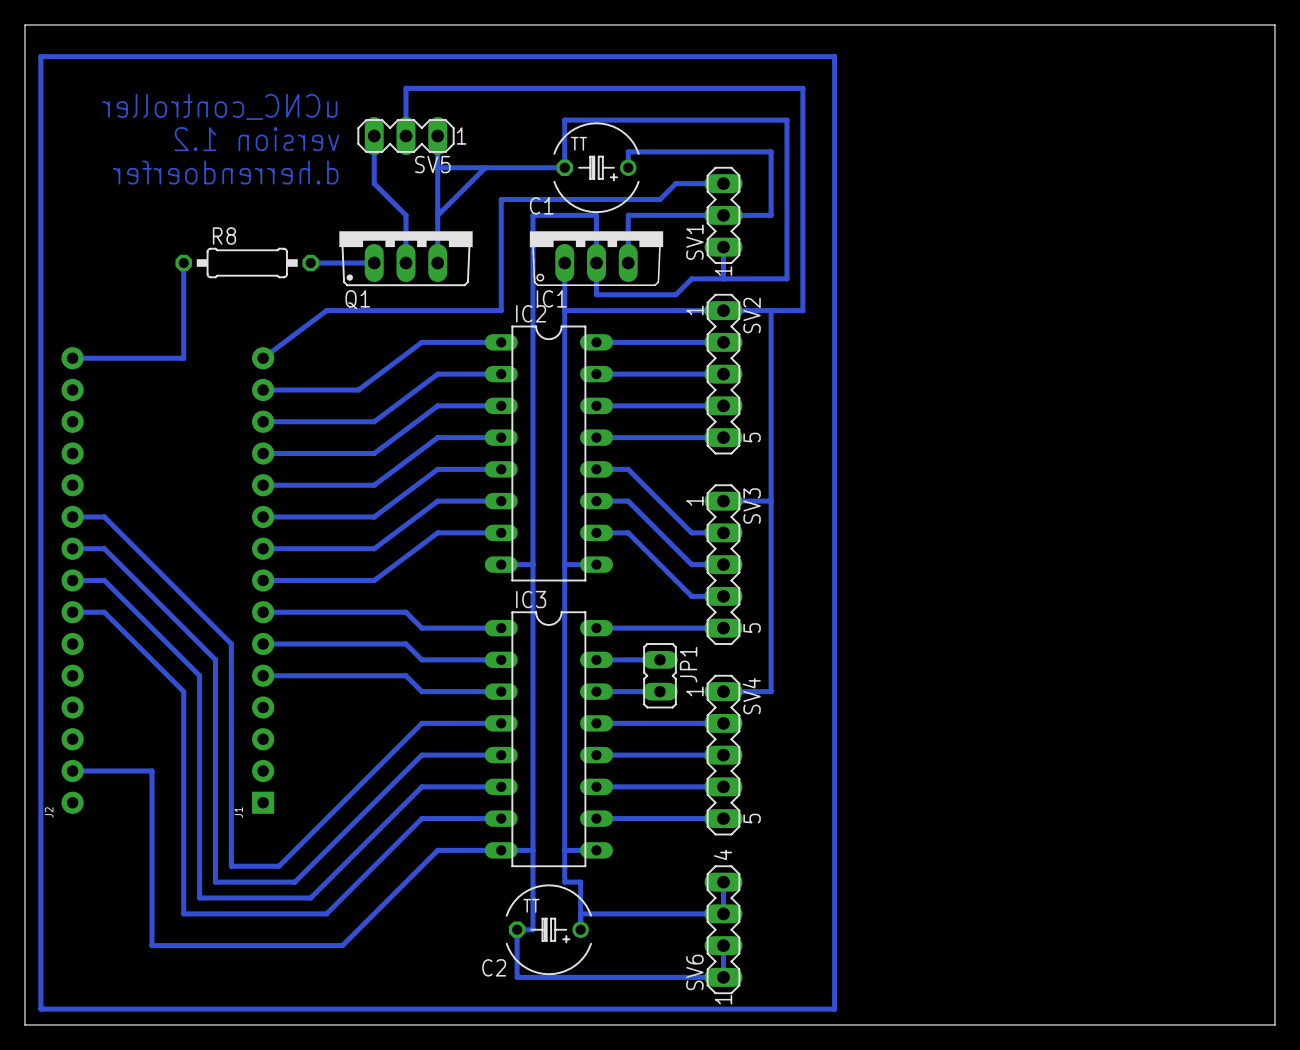
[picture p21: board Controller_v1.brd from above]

Board: 2 copper layers, 100.0 x 80.0 mm, 16 parts (0 on the bottom side), 35 nets.

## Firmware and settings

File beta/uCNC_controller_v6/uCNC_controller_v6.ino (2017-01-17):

/*
 * This file is part of uCNC_controller.
 *
 * Copyright (C) 2016,2017  D.Herrendoerfer
 *
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
 *   You should have received a copy of the GNU General Public License
 *   along with uCNC_controller.  If not, see <http://www.gnu.org/licenses/>.
 */

#include "uCNC_controller.h"
#include "uCNC_stepper_lt.h"
#include "uCNC_machine.h"
#include "uCNC_servo.h"

volatile long stepposX = 0;
volatile long stepposY = 0;
volatile long stepposZ = 0;
volatile long stepposE = 0;

volatile long servopos = 0;

//Stepper mStepperX(8,10,9,11,1);
//Stepper mStepperY(4,6,5,7,1);            
//Stepper mStepperZ(17,19,16,18,1);
Stepper mStepperEMU(&stepposE);
Servo mServo(12);

//Servo mServo(12, &servopos);

void setup()
{
  timer1_setup();
  setupIoThread();
  
  Serial.begin(9600);
}

unsigned long time;
unsigned long next_IO_mseconds;

void loop()
{ 
  mStepperX.attachEmu(&stepposX);
  mStepperY.attachEmu(&stepposY);
  mStepperZ.attachEmu(&stepposZ);

  mServo.attach(&servopos);
  mServo.start();
  
  int shutdown = 0;
  unsigned long starttime = 0;
  unsigned long stoptime = 0;
  
  Serial.println("uCNC_controller_v6 (compatible: Grbl v0.81, Repetier 0.80, E3D v1.00)");

  // prepare the next clock tick
  next_IO_mseconds = millis() + 250; // First IO in 250ms

  while (!shutdown) {
    time = millis();

    if ( (long)(time - next_IO_mseconds) >= 0 ) {
      next_IO_mseconds += 10;
      
      handleIO();  
    }
    
    
/*
    Serial.println("test");

    Serial.println("Servo");

    servopos = -90;
    delay(5000);
    servopos = 0;
    delay(5000);
    servopos = 90;
    delay(5000);

    for (int i=-90; i < 90; i++) {
      servopos=i;
      delay(10);
    }
    for (int i=90; i > -90; i--) {
      servopos=i;
      delay(10);
    }

    for (int i=-90; i < 90; i++) {
      servopos=i;
      delay(5);
    }
    for (int i=90; i > -90; i--) {
      servopos=i;
      delay(5);
    }

    for (int i=-90; i < 90; i++) {
      servopos=i;
      delay(5);
    }
    for (int i=90; i > -90; i--) {
      servopos=i;
      delay(5);
    }

    servopos = 0;
    delay(5000);

    mServo.stop();
    mServo.attach(&stepposE);
    mServo.start();

    
    Serial.println("Emu");

    mStepperEMU.update(1);
    Serial.println(stepposE);
    mStepperEMU.update(1);
    Serial.println(stepposE);
    mStepperEMU.update(1);
    Serial.println(stepposE);
    mStepperEMU.update(-1);
    Serial.println(stepposE);

    for (int i=0; i < 90; i++) {
      mStepperEMU.update(1);
      delay(5);
    }

    for (int i=0; i < 180; i++) {
      mStepperEMU.update(-1);
      delay(5);
    }

    for (int i=0; i < 90; i++) {
      mStepperEMU.update(1);
      delay(5);
    }

    Serial.println("Real");

    plan_line(4096, 0, 0, 0.8);
    
    starttime = micros();
    if (mStepperX.busy() || mStepperY.busy() || mStepperZ.busy()) {
      mStepperX.tick();
      mStepperY.tick();
      mStepperZ.tick();
    }
    stoptime = micros();

    delay(1);

    while (mStepperX.busy() || mStepperY.busy() || mStepperZ.busy()) {
      mStepperX.tick();
      mStepperY.tick();
      mStepperZ.tick();
      delayMicroseconds(800);
    }
    
    Serial.print("Stepper Pos(X) :");
    Serial.println(stepposX);
    Serial.print("Stepper Pos(Y) :");
    Serial.println(stepposY);
    Serial.print("Stepper Pos(Z) :");
    Serial.println(stepposZ);

    Serial.print("Time for one slot :");
    Serial.print(stoptime - starttime);
    Serial.println("uS");

    plan_line(0, 4096, 0, 100);

    while (mStepperX.busy() || mStepperY.busy() || mStepperZ.busy()) {
      mStepperX.tick();
      mStepperY.tick();
      mStepperZ.tick();
      delayMicroseconds(800);
    }
    Serial.print("Stepper Pos(X) :");
    Serial.println(stepposX);
    Serial.print("Stepper Pos(Y) :");
    Serial.println(stepposY);
    Serial.print("Stepper Pos(Z) :");
    Serial.println(stepposZ);

    plan_line(0, 0, 4096, 100);

    while (mStepperX.busy() || mStepperY.busy() || mStepperZ.busy()) {
      mStepperX.tick();
      mStepperY.tick();
      mStepperZ.tick();
      delayMicroseconds(800);
    }
    Serial.print("Stepper Pos(X) :");
    Serial.println(stepposX);
    Serial.print("Stepper Pos(Y) :");
    Serial.println(stepposY);
    Serial.print("Stepper Pos(Z) :");
    Serial.println(stepposZ);

    plan_line(-1024, 2048, 4096, 100);

    starttime = micros();
    if (mStepperX.busy() || mStepperY.busy() || mStepperZ.busy()) {
      mStepperX.tick();
      mStepperY.tick();
      mStepperZ.tick();
    }
    stoptime = micros();
    
    delay(1);

    while (mStepperX.busy() || mStepperY.busy() || mStepperZ.busy()) {
      mStepperX.tick();
      mStepperY.tick();
      mStepperZ.tick();
      delayMicroseconds(800);
    }

    Serial.print("Time for three slots :");
    Serial.print(stoptime - starttime);
    Serial.println("uS");

    Serial.print("Stepper Pos(X) :");
    Serial.println(stepposX);
    Serial.print("Stepper Pos(Y) :");
    Serial.println(stepposY);
    Serial.print("Stepper Pos(Z) :");
    Serial.println(stepposZ);

    Serial.println("done.");
    
    Serial.print("Using timer :");
    plan_line(0, 0, 0, 3.8);
    start_timer();
    
    while (!timer_idle) {
      delay(20);
    }

    Serial.print("done.");
    
    delay(20000);
*/
  }
}

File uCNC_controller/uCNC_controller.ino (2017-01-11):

/*
 * This file is part of uCNC_controller.
 *
 * Copyright (C) 2014  D.Herrendoerfer
 *
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
 *   You should have received a copy of the GNU General Public License
 *   along with uCNC_controller.  If not, see <http://www.gnu.org/licenses/>.
 */

#include <Servo.h>
#include <Stepper.h>

/* Version of this progam */
float uCNC_Version = 1.0;

/* Development functions - broken code*/
//#define BUILTIN 1
//#define BROKEN 1

/* Conversion factor of steps per millimeter */
float stepsPerMillimeter_X = 200 / 17.1;
float stepsPerMillimeter_Y = -200 / 17.1;
float stepsPerMillimeter_Z = 200 / 17.1;

/* Unit conversion factor */
float conversionFactor = 1;  // 1 for mm 25.4 for inches

/* Stepper library initialization */
const int stepsPerRevolution = 200;  // change this to fit the number of steps per revolution
Stepper myStepper1(stepsPerRevolution, 8,9,10,11);
Stepper myStepper2(stepsPerRevolution, 4,5,6,7);            
Stepper myStepper3(stepsPerRevolution, 17,16,19,18);

/* Servo functions and limits */
Servo myServo;

int servoPosMax=83;
int servoPosMin=70;
int servoToolInc=10;
float servoPosZfactor=1.0;

/* Mode selector for the motors (see documentation) */
int   motorMode = 0;

/* X,Y,Z in absolute steps position */
int X = 0;
int Y = 0;
int Z = 0;

/* X,Y,Z in measurement value*/
float posX = 0.0;
float posY = 0.0;
float posZ = 0.0;

/* Tools and Feeds and Coolants */
int tool     = 0;
int spindle  = 0;
int coolant1 = 0;
int coolant2 = 0;

/* Spindle speed (M3 parameter)*/
int spindleSpeed = 0;

int led = 13;

#define COMMAND_SIZE 128
uint8_t command_line[COMMAND_SIZE];
uint8_t sin_count=0;
uint16_t no_data = 0;
uint8_t asleep = 0;


void setup() {
  Serial.begin(9600);
  Serial.println("uCNC_controller (compatible: Grbl v0.81, Repetier 0.80, E3D v1.00)");
  
  // LED (Laser output)
  pinMode(led, OUTPUT);
  // General pupose (coolant 1) output
  pinMode(2, OUTPUT);
  // General pupose (coolant 2) output
  pinMode(3, OUTPUT);
  
  /* Init the steppers and servo */
  initMotors();
}

void clear_command_string() {
  for (int i=0; i<COMMAND_SIZE; i++) 
    command_line[i] = 0;
  sin_count = 0;
}

void loop() {
  uint8_t c;
  
  Serial.println("ready");

  while (true) {
    //read in characters if we got them.
    if (Serial.available() > 0)   {
      c = (uint8_t)Serial.read();
      no_data = 0;
      asleep = 0;
      command_line[sin_count++] = c;
    }
    else {
      no_data++;
      delayMicroseconds(150);
    }
  
    if (sin_count && (c == '\n' || no_data > 100)) {
      command_line[sin_count] = 0;
      process_command(command_line);
      //sin_count=0; 
      clear_command_string(); 
    }
  
    if (no_data == 60000)  {
      if (!asleep) {
        powerdown();
        asleep=1;
      }
    }
  }
}

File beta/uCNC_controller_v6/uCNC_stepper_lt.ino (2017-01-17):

/*
 * This file is part of uCNC_controller.
 *
 * Copyright (C) 2016,2017  D.Herrendoerfer
 *
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
 *   You should have received a copy of the GNU General Public License
 *   along with uCNC_controller.  If not, see <http://www.gnu.org/licenses/>.
 */

/* README:
This file contains the drivers for 3 types of stepper controllers.
By choosing the appropriate constructor you choose the driver.
Available are:

2Pin: Bipolar driver for double-h bar driver chips
3pin: Bipolad driver for A4988 or similar chips with direction and step 
      interface and enable
4pin: Unipolar stepper driver for use with ULN2003/2004 driver ICs
*/

#ifdef STEPPER_2PIN
/*
 * two-wire constructor.
 * Sets which wires should control the motor.
 */
Stepper::Stepper(int motor_pin_1, int motor_pin_2)
{
  this->step_number = 0;        // which step the motor is on
  this->speed = 0;              // the motor speed, in Hz
  this->last_step = 0;
  this->halfstep = hstep;

  // Arduino pins for the motor control connection:
  this->motor_pin_1 = motor_pin_1;
  this->motor_pin_2 = motor_pin_2;

  // setup the pins on the microcontroller:
  pinMode(this->motor_pin_1, OUTPUT);
  pinMode(this->motor_pin_2, OUTPUT);

  // When there are only 2 pins, set the other two to 0:
  this->motor_pin_3 = 0;
  this->motor_pin_4 = 0;

  // pin_count is used by the stepMotor() method:
  this->pin_count = 2;

  // fix the position value pointer to 0
  this->motor_pos_emu = 0;
}
#endif

#ifdef STEPPER_3PIN
/*
 * three-wire constructor.
 * Sets which wires should control the motor.
 * pin 1: direction
 * pin 2: step
 * pin 3: enable(inverted)
 */
Stepper::Stepper(int motor_pin_1, int motor_pin_2, int motor_pin_3)
{
  this->step_number = 0;      // which step the motor is on
  this->speed = 0;            // the motor speed, in Hz
  this->last_step = 0;

  // Arduino pins for the motor control connection:
  this->motor_pin_1 = motor_pin_1;
  this->motor_pin_2 = motor_pin_2;
  this->motor_pin_3 = motor_pin_3;

  // setup the pins on the microcontroller:
  pinMode(this->motor_pin_1, OUTPUT);
  pinMode(this->motor_pin_2, OUTPUT);
  pinMode(this->motor_pin_3, OUTPUT);

  // When there are only 3 pins, set the other one to 0:
  this->motor_pin_4 = 0;

  // pin_count is used by the stepMotor() method:
  this->pin_count = 3;

  // fix the position value pointer to 0
  this->motor_pos_emu = 0;
}
#endif


#ifdef STEPPER_4PIN
/*
 *   constructor for four-pin version
 *   Sets which wires should control the motor.
 */
Stepper::Stepper(int motor_pin_1, int motor_pin_2, int motor_pin_3, int motor_pin_4, int hstep)
{
  this->step_number = 0;        // which step the motor is on
  this->speed = 0;              // the motor speed, in Hz
  this->last_step = 0;
  this->halfstep = hstep;

  // Arduino pins for the motor control connection:
  this->motor_pin_1 = motor_pin_1;
  this->motor_pin_2 = motor_pin_2;
  this->motor_pin_3 = motor_pin_3;
  this->motor_pin_4 = motor_pin_4;

  // setup the pins on the microcontroller:
  pinMode(this->motor_pin_1, OUTPUT);
  pinMode(this->motor_pin_2, OUTPUT);
  pinMode(this->motor_pin_3, OUTPUT);
  pinMode(this->motor_pin_4, OUTPUT);

  // pin_count is used by the stepMotor() method:
  this->pin_count = 4;

  // fix the position value pointer to 0
  this->motor_pos_emu = 0;
}
#endif

#ifdef STEPPER_EMULATION
/*
 * Emulation constructor.
 * Solely operates on a memory value.
 */
Stepper::Stepper(volatile long *motor_pin_1 )
{
  this->step_number = 0;        // which step the motor is on
  this->speed = 0;              // the motor speed, in Hz
  this->last_step = 0;

  // Arduino pins for the motor control connection:
  this->motor_pos_emu = motor_pin_1;

  // When not using any pins, set them to 0:
  this->motor_pin_1 = 0;
  this->motor_pin_2 = 0;
  this->motor_pin_3 = 0;
  this->motor_pin_4 = 0;

  // pin_count is used by the stepMotor() method:
  this->pin_count = 0;
}
#endif

/*
  Sets the speed in steps per second (or Hz)
*/
void Stepper::setSpeed(int whatSpeed)
{
  this->speed = whatSpeed;
}

int Stepper::getSpeed()
{
  return(this->speed);
}

void Stepper::setSlack(int slack)
{
  this->slack = slack;
}

int Stepper::getSlack()
{
  return (this->slack);
}

void Stepper::plan(int seq_number, int direction, posval_t abssteps, posval_t deltaabs, posval_t startval, unsigned int Hz, unsigned int startHz)
{
  this->plan_direction = direction;
  this->plan_abssteps = abssteps;
  this->plan_deltaabs = deltaabs;
  this->plan_startval = startval;
  
  this->plan_steps = abssteps;
  this->plan_seqno = seq_number;
  this->plan_active = true;
  this->plan_Hz = Hz;
  this->plan_startHz = startHz;
}

int Stepper::getHz()
{
  return (this->plan_Hz);
}

void Stepper::tick()
{
  if(!this->plan_active)
    return;
  
  this->plan_steps--;
  
  this->plan_startval += this->plan_deltaabs;
  if(this->plan_startval >= this->plan_abssteps){
    this->plan_startval -= this->plan_abssteps;
    stepMotor(this->plan_direction);
  }
  
  if (!plan_steps) {
    this->plan_active=false;
  }
}

int Stepper::busy()
{
  return (this->plan_active);
}

/*
  Moves the stepper exactly one step forward or back
 */
void Stepper::update(int step_to_move)
{
  int step;
  
  if (step_to_move == 0)
    return;
  
  step = sgn(step_to_move);
  
  stepMotor(step);
}

/*
 * Reset the steppers emulated position.
 */
void Stepper::resetEmu()
{
  *this->motor_pos_emu = 0;
}

/*
 * Attach a variable to store the emulated position.
 */
void Stepper::attachEmu(volatile long *emu)
{
  this->motor_pos_emu = emu;
}

/*
 * Moves the motor forward or backwards.
 */
void Stepper::stepMotor(int step)
{
  int thisStep;
  
  this->step_number += step;
  this->last_step = step;

  if(this->motor_pos_emu)
    *this->motor_pos_emu += step;

#ifdef STEPPER_2PIN
  if (this->pin_count == 2) {
    thisStep = this->step_number % 4;
    
    switch (thisStep) {
      case 0: /* 01 */
      digitalWrite(motor_pin_1, LOW);
      digitalWrite(motor_pin_2, HIGH);
      break;
      case 1: /* 11 */
      digitalWrite(motor_pin_1, HIGH);
      digitalWrite(motor_pin_2, HIGH);
      break;
      case 2: /* 10 */
      digitalWrite(motor_pin_1, HIGH);
      digitalWrite(motor_pin_2, LOW);
      break;
      case 3: /* 00 */
      digitalWrite(motor_pin_1, LOW);
      digitalWrite(motor_pin_2, LOW);
      break;
    }
    return;
  }
#endif

#ifdef STEPPER_3PIN
  if (this->pin_count == 3) {
    /*Enable stepper driver*/
    digitalWrite(motor_pin_3, LOW);
    /*Set direction pin*/
    digitalWrite(motor_pin_1,(step==1));
    /*Pulse step line*/
    digitalWrite(motor_pin_2, HIGH);
    delayMicroseconds(1);
    digitalWrite(motor_pin_2, LOW);
    return;
  }
#endif
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

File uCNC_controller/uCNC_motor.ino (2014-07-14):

/*
 * This file is part of uCNC_controller.
 *
 * Copyright (C) 2014  D.Herrendoerfer
 *
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
 ********************************************************************************
 *
 *  From the documentation: These are the supported modes for the steppers 
 *                           and light/servo drivers
 *                           
 *	M150: Set Z-Axis mode
 *	---------------------
 *	Defines the mode how the Steppers, the servo and the laser driver are
 *	used by the controller and which codes modify their states
 *	  Mode 0: Stepper 1 is X
 *	          Stepper 2 is Y
 *	          Stepper 3 is Z
 *	          Servo is spindle speed
 *
 *	          
 *	  Mode 1: Stepper 1 is X
 *	          Stepper 2 is Y
 *	          Stepper 3 is Y
 *	          Servo     is Z (down for Z<0)
 *	          Laser     is Z (on for Z<0)
 *	
 *	  Mode 2: Stepper 1 is X
 *	          Stepper 2 is Y
 *	          Stepper 3 is Y
 *  	          Servo     is Z (+90 to -90)
 * 	          Laser     is driven by spindle
 *	          
 *	  Mode 3: Stepper 1 is X
 *	          Stepper 2 is Y
 *	          Stepper 3 is Y
 *	          Servo     is tool
 *  	          Laser     is Z (on for Z<0)
 *	          
 *	  Sample:
 *	    M150 S2   ;Sets mode 2
 *
 *
 */

/* IMPORTANT: All direct motor controls are here, everywhere else
              these functions here are used to keep this code portable 
              
              The functions are grouped into those using the native steps
              values or the measurement (float) values. */

#define MAX_SPEED 60
#define DRILL_SPEED 0.1

float motorSpeed = MAX_SPEED;

void initMotors()
{
  myStepper1.setSpeed(MAX_SPEED);
  myStepper2.setSpeed(MAX_SPEED);
  myStepper3.setSpeed(MAX_SPEED);

  myServo.attach(12);
  myServo.write(servoPosMax);

  myStepper1.step(-1400);
  myStepper2.step(-1500);

  myStepper2.step(400);
  myStepper1.step(75);
}

void setXYSpeed(float speed)
{
  // remember
  motorSpeed = speed;

  if (speed == 0 || speed > 1) {
    speed = MAX_SPEED;
  }
  else {
    speed *= MAX_SPEED;
  }
  
  myStepper1.setSpeed((int)speed);
  myStepper2.setSpeed((int)speed);
  myStepper3.setSpeed((int)speed);
  
}

void moveX(int dX)
{
  X = X + dX;
  myStepper1.step(dX);
}

void moveY(int dY)
{
  Y = Y + dY;
  
  switch(motorMode) {
  case 0:
    myStepper2.step(dY);
    break;
  case 1:
  case 2:
  case 3:
    int i;
    for (i=0;i<abs(dY);i++) {
      myStepper3.setSpeed(MAX_SPEED); //stepper3 is always driven with stepper2
      myStepper3.step((dY < 1) ? -1 : 1);
      myStepper2.step((dY < 1) ? -1 : 1);
    }
    break;
  }  
}

void resetXY()
{
  Y = 0;
  X = 0;
}

void penDown()
{
  delay(30);
  digitalWrite(led, HIGH);
  myServo.write(servoPosMin);
  delay(100);
}

void penUp()
{
  digitalWrite(led, LOW);
  myServo.write(servoPosMax);
  delay(100);
}

void updateServo(int servoPos)
{
  if (servoPos>servoPosMax)
    servoPos = servoPosMax;
  if (servoPos<servoPosMin)
    servoPos = servoPosMin;
  
  myServo.write(servoPos);
}

void servoZ()
{
  int servoPos = ((float)posZ*servoPosZfactor) + 90;
  updateServo(servoPos);
}

void moveZ(int dZ)
{
  Z = Z + dZ;  

  switch(motorMode) {
  case 0:
    myStepper3.setSpeed((int)motorSpeed); //stepper3 is always driven with stepper2
    myStepper3.step(dZ);
    break;
  case 1:
    digitalWrite(led,(posZ < 1) ? HIGH : LOW);
    updateServo((posZ < 1) ? servoPosMin : servoPosMax);
    delay(100);
    break;
  case 2:
    updateServo(servoPosMin + (servoPosZfactor*posZ));
    delay(200);
    break;
  case 3:
    digitalWrite(led,(posZ < 1) ? HIGH : LOW);
    break;
  }
}

void powerdown()
{
  // Stepper 1
  digitalWrite(4,LOW);
  digitalWrite(5,LOW);
  digitalWrite(6,LOW);
  digitalWrite(7,LOW);
  // Stepper 2  
  digitalWrite(8,LOW);
  digitalWrite(9,LOW);
  digitalWrite(10,LOW);
  digitalWrite(11,LOW);
  // Stepper 3  
  digitalWrite(16,LOW);
  digitalWrite(17,LOW);
  digitalWrite(18,LOW);
  digitalWrite(19,LOW);
}

void updateMotorCodes()
{
  digitalWrite(2,(coolant1 == 1) ? HIGH : LOW);
  digitalWrite(3,(coolant2 == 1) ? HIGH : LOW);
  
  switch(motorMode) {
  case 0:
    myServo.write(spindleSpeed);
    digitalWrite(led,(spindle == 1) ? HIGH : LOW);
    break;
  case 2:
    digitalWrite(led,(spindle == 1) ? HIGH : LOW);
    break;
  }
}

void updateToolCodes()
{
  if (motorMode == 3) {
    updateServo(servoPosMin + (tool * servoToolInc));
  }
}

/* No direct IO below this line */

void moveToX(int pX)
{
  moveX(pX - X);
}

void moveToY(int pY)
{
  moveY(pY - Y);
}

void moveToXY(int pX, int pY)
{
  moveX(pX - X);
  moveY(pY - Y);
}

void moveToXYZ(int pX, int pY, int pZ)
{
  if (pX - X)
    moveX(pX - X);
  if (pY - Y)
    moveY(pY - Y);
  if (pZ - Z)
    moveZ(pZ - Z);
}

void drill()
{
  int oZ;
  float oSpeed;
  
  delay(500);
  oZ = Z;
  oSpeed=motorSpeed;
  
  setXYSpeed(DRILL_SPEED);
  
  moveToXYZ(X,Y,Z-(10*stepsPerMillimeter_X));
  delay(500);
  setXYSpeed(oSpeed);
  moveToXYZ(X,Y,oZ);
}

int sgn(int value)
{
  return value < 0 ? -1 : value > 0;
}

void lineXYZ(int x2, int y2, int z2)
{
  int n, deltax, deltay, deltaz, sgndeltax, sgndeltay, sgndeltaz, deltaxabs, deltayabs, deltazabs, x, y, z, drawx, drawy, drawz;

  deltax = x2 - X;
  deltay = y2 - Y;
  deltaz = z2 - Z;
  deltaxabs = abs(deltax);
  deltayabs = abs(deltay);
  deltazabs = abs(deltaz);
  sgndeltax = sgn(deltax);
  sgndeltay = sgn(deltay);
  sgndeltaz = sgn(deltaz);
  x = deltayabs >> 1;
  y = deltaxabs >> 1;
  z = deltazabs >> 1;
  drawx = X;
  drawy = Y;
  drawz = Z;
  
  moveToXYZ(drawx, drawy, drawz);
  
  // dX is biggest
  if(deltaxabs >= deltayabs && deltaxabs >= deltazabs){
    for(n = 0; n < deltaxabs; n++){
      y += deltayabs;
      if(y >= deltaxabs){
        y -= deltaxabs;
        drawy += sgndeltay;
      }
      z += deltazabs;
      if(z >= deltaxabs){
        z -= deltaxabs;
        drawz += sgndeltaz;
      }

      drawx += sgndeltax;
      moveToXYZ(drawx, drawy, drawz);
    }
    return;
  }
  // dY is biggest
  if(deltayabs >= deltaxabs && deltayabs >= deltazabs){
    for(n = 0; n < deltayabs; n++){
      x += deltaxabs;
      if(x >= deltayabs){
        x -= deltayabs;
        drawx += sgndeltax;
      }
      z += deltazabs;
      if(z >= deltayabs){
        z -= deltayabs;
        drawz += sgndeltaz;
      }
      drawy += sgndeltay;
      moveToXYZ(drawx, drawy, drawz);
    }
    return;
  }
  // dZ is biggest
  if(deltazabs >= deltaxabs && deltazabs >= deltayabs){
    for(n = 0; n < deltazabs; n++){
      x += deltaxabs;
      if(x >= deltazabs){
        x -= deltazabs;
        drawx += sgndeltax;
      }
      y += deltayabs;
      if(y >= deltazabs){
        y -= deltazabs;
        drawy += sgndeltay;
      }
      drawz += sgndeltaz;
      moveToXYZ(drawx, drawy, drawz);
    }
    return;
  }
}

void drawline(int x1, int y1, int x2, int y2)
{
  penUp();
  lineXYZ(x1,y1,5);
  penDown();
  lineXYZ(x2,y2,-5);
  penUp();
}

/* No direct use of step coordinates below this line */
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

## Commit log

2014-04-24 This commit adds the files needed to produce a small plotter that will work with this firmware. Included is the layout of a controller board and 3D files to print the required parts for the plotter i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
    [Controller.brd, Plotter-v3-x-bridge-2.stl, Plotter-v3-x-bridge.stl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]
2014-07-14 Fix erroreous stepper speed setting in mode 1
    [uCNC_motor.ino]
2014-08-01 Update the stl files for the plotter to better work with slic3r.
    [Plotter-v3-x-bridge-1.stl, Plotter-v3-x-bridge-2.stl, Plotter-v3-x-bridge.stl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]
2014-09-30 Add the files for the version 4 plotter, firmware, and controller.
    [Controller_v4.brd, Controller_v4.sch]
2014-11-18 Fix initializarion and position reset
    [uCNC_controller.ino, uCNC_motor.ino, uCNC_stepper.ino]
2014-12-03 Organize the file and directory structure so sketches are easier to directly open in Arduino IDE if the git has been downloaded as a zip file (hopefully)
2014-12-28 Add schematic and board for the reworked v1 controller board.
    [Controller_v1.brd, Controller_v1.sch]
2015-05-11 Fixed an initialization bug.
    [uCNC_controller_v4.ino]
2015-07-07 Added GRBL Polulu shield output layout
2015-07-08 Updates for GRBL-Shield support
2015-07-08 Add some cleanup and changes for the GRBL Shield. Also fix some minor issues with Z-Axis handling
    [uCNC_controller_v4.ino, uCNC_motor.ino]
2016-04-18 Fixed a nasty bug that would hit if the build area was bigger than 32k native steps.
    [uCNC_motor.ino]
2016-04-18 Fixed the same nasty 32k steps bug in the beta of the v1 firmware
    [uCNC_motor.ino]
2016-12-27 Add v3 AllParts stl file
    [Plotter-v3-AllParts.stl]
2016-12-31 Add v4 plotter files
    [Plotter_v4_AllParts.stl]
2017-01-11 Fix servo init timing issue
    [uCNC_controller_v4.ino, uCNC_motor.ino]
2017-01-12 Work to revive auto homing
2017-01-13 Back to conservative defaults for homing
2017-01-17 Push v6 beta to newest version, adding alpha servo support
2017-02-15 Add first set of parts to Rod-Robin CNC build
    [Rod-Robin-H-Base-A.stl, Rod-Robin-H-Base-B.stl, Rod-Robin-H-Base-C.stl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]
2017-05-25 Adding new code from recent projects
    [uControl_v1.brd, uControl_v1.sch]
2017-09-23 Add simple engraver support with spindle-on/off semantics
2017-10-09 Introduce V1_COMPACT board definition
2017-11-02 Add the LED-HMD code
2017-12-22 Slight rework to make board definitions more apparent.
    [grbl_board.h, uCNC_controller_v4.ino, uCNC_motor.ino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]
2017-12-22 Also add the other board definition files
2018-01-10 Add STL files for each single part of Plotter_v4
    [Plotter_v4_Pillar_1.stl, Plotter_v4_Pillar_2.stl, Plotter_v4_Table_Base_1.stl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]
2018-05-26 Typo fixes
    Fixed typos in the word application and the word millimeter.
